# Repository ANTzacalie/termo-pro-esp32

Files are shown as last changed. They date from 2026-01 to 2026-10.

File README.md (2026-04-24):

# ESP32 Smart Thermostat (V1)

<p align="center">







</p>

A fully functional, smart thermostat built on the ESP32 platform using the ESP_NOW protocol for wireless communication. This unit features 6 programmable modes, a persistent flash-memory system, and an automated brightness control system.

## 💎 Features

- **Protocol:** ESP-NOW for fast, low-power communication with heating units.  
- **Storage:** All programs and settings are stored in Flash memory (NVS) to prevent data loss during power outages.  
- **Display:** 16x2 LCD providing real-time data and a menu-driven configuration system.  
- **Auto-Brightness:** Integrated photoresistor (LDR) logic that adjusts LCD backlight based on ambient light.  

- **Programs:**  
  - **Program B (Basic):** Pre-configured (Start: 21°C / Stop: 23°C).  
  - **Programs 1–5:** User-programmable (Empty by default).  
  - **Program 6/A:** Dedicated Comfort/Auto mode.  

---

## 🖥 User Interface Guide

### Main Interface [A]

This is the default screen. It displays the following layout:  

`T: vv.v H: vv.v PN XX:XX DAY[N] D/N O/F`

| Indicator | Description |
|---|---|
| T | Current Temperature (Celsius) |
| H | Relative Humidity (%RH) |
| P | Program Mode |
| N | Program ID Number |
| XX:XX | Current Time (Hours:Minutes) |
| DAY [N] | Current Day of the week (1–7) |
| D/N | Day / Night Status |
| O/F | Heating Status (On / Off) |

---

### Navigation & Settings [B]

To access the configuration menu, press and hold **Button 1** for **2 seconds**.  

> **Note:** Entering Interface [B] pauses the thermostat's main control logic until you exit.

#### Controls in Menus

- **Button 2:** Moves the cursor (indicated by an arrow `->`).  
- **Button 1:** Selects the highlighted option or increments values.  

#### Menu Options

- **SPG (Select Program):** Choose which of the 6 programs to activate. Selecting a program returns you to Menu [B].  

- **EPG (Edit Program):**  
  - Select the program you wish to modify.  
  - Line 1 shows the Program ID; Line 2 shows Start Temperature and Stop Temperature.  
  - Button 2 selects the value; Button 1 increments the temperature.  
  - **Save Logic:** After 10 seconds of inactivity, the data is saved to memory, set as the active program, and the system returns to Menu [B].  

- **ETM (Edit Time):**  
  - Modify Hour, Minute, and Day.  
  - Button 2 moves the cursor; Button 1 increments the value.  
  - **Save Logic:** Settings save automatically after 10 seconds of inactivity.  

- **EXIT:** Returns to the Main Interface [A].  

---

## 🛠 Special Commands & Manual Overrides

These actions are performed directly from the Main Interface [A] using timed button presses:

| Action | Button Combo | Duration | Result |
|---|---|---|---|
| System Restart | Button 1 + Button 2 | 15 Seconds | Device reboots |
| Manual Mode | Button 2 | 5 Seconds | Disables auto-logic and active program |
| Manual OFF | Button 2 | 5 Seconds | While in Manual Mode: Turns off the heating module |
| Manual ON | Button 1 + Button 2 | 10 Seconds | While in Manual Mode: Turns on the heating module |
| Exit Manual | Button 2 | 10 Seconds | Cancels manual control and restores Auto Program logic |

---

## 🚀 Future Roadmap - V2 ;)
- An PCB and 3D printed case, also improved functionalities and better starting module microcontroller.
- 📱 **Mobile Application:** A dedicated app for Android to control the thermostat remotely via Bluetooth (BLE). This will allow for easy program editing and manual overrides without using the physical buttons.

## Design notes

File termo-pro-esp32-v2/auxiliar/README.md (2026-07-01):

**** Thermostat Unit ****

- 1 x WC1602A Display;
- 1 x ESP32WROOM32-NodeMCU32S 38pin Devkit;
- 1 x DHT11 Temperature&Humidity Sensor;
- 1 x Buzzer;
- 1 x 8PIN_P2.54mm USB-C Soldered module;
- 1 x 1N4007 Diode(smaller one work too);
- 4 x 6mm tactile buttons;
- 2 x 10k resistors;
- 1 x 1k resistor;
- 1 x 330 ohm resistor;
- 1 x 10k RM65 potentiometer;
- 1 x 10k LDR Photoresistor;
- 2 x PN2222A BJT NPN Transistors;
- 2 x 50V 220nF capacitors;
- 1 x 16V 680uF capacitor;
- 1 x 25V 220uF capacitor;

**** Starting Unit ****

- 1 x ESP32-C3-Supermini Devkit 16pin;
- 1 x 8PIN_P2.54mm USB-C Soldered module;
- 1 x 220 ohm resistors; *P1*
- 2 x 50 ohm resistor;  *P1*
- 1 x 330 ohm resistor;
- 1 x 10k resistor;
- 1 x 25V 220uF capacitor;
- 1 x 50V 220nF capacitor;
- 1 x 10V 470uF capacitor;
- 1 x 12mm tactile LED(1.8V) button; *P1*
- 1 x PN2222A BJT NPN Transistor;
- 1 x Rectangular GREEN LED(3V); *P1*
- 1 x Rectangular RED LED(3V); *P1*
- 2 x Screw Terminal Blocks P5.08 - 5mm;
- 1 x 1N4007 Diode;
- 1 x SRD_FORM_C 5V Relay;

*P1* -> Resistor values for each LED is calculated based on the internal diode forward voltage using Ohm Law !
I recommand having LED of the same forward voltage, so you can get equal brightness.

///////////////////////////////////// ELECTRICAL IMPLEMENTATION ////////////////////////////////////

--------- Starting Unit ---------

- Relay flyback diode -> diode that can handle minimum 200mA, I have chosen 1N4007 because is cheap and easy to find, and handles a maximum of 1A.
- PN2222A NPN BJT Transistor, its cheap and good for general use as a switch, using a MOSFET is more expensive.
- Resistance of the transistor that drives the relay is calculated using Ohm law, the relay takes around 80mA, taking a B = 10 as minimum , we need ~7-8 mA in transistor base , an 330 Ohm resistance is used because:
I = U / R => I = (3.3 - 0.7(TB)) / 330 => I ~ 7.8 mA , so 330 ohm is enough to saturate the transistor for optimal operation.
- 10k B3950A thermistor, to be read by ADC pin requires another 10k resistor to form a tension divider for reading to be possible.
- 12.5mm LED button requires an 470 ohm resistor because internal diode uses 1.8V an 220 ohm resistance is used => I = 3.3 - 1.8 / 220 => I = 6.8mA , that is decent in brightness.
- The 2 LED , green and red, used 50 ohm used for both , because red is 3V and green is also 3V , so they are close in luminosity, also current is under 7mA per pin.
- Capacitor values C1,C2 and C3:
*C1 is the main capacitor that is positioned at the begining of the USB-C 5VDC, the value of 220uF is chosen to surpress current spikes for the general circuit(not the ESP32-C3-Supermini, not complete);
*C3 is the main capacitor positioned close to the ESP32-C3 with a value of 470uF , this and C1 in combination is to surpress the current spikes of the ESP32-C3, as calculated by tge formula:
C = I * dt / dV => C = 0.335A(spike current) * 0.0005s(500us) / 0.3V(averge) => C = 558uF, this value is not easy to find so C3 is 470uF and C1 compensates, capacitor in paralel sum capacitance, so C1,3 = 690uF, that is enough;
*C2 the 220nF capacitor si placed very close to the ESP32 5V(VIN) pin , this is used for bypass.

Total Power Consumption(P = I x V) => 335mA x 5V + 80mA x 5V + 2x6mA x 0.3V + 200uA x 3.3V + 6.8mA x 1.5V => P =  2.089W ~ 2.1W

--------- Termostat Unit ---------

- WC1602A display has a 10k Potentiometer for contrast control.
- Buzzer flyback diode 1N4007, same reason as for the relay.
- Transistor BJT NPN PN2222A driving the buzzer has a base resistance of 1kOhm, enough to saturate it I = 3.3 - 0.7 / 1kOhm => I ~ 2.6mA , buzzer takes from 15mA to 30mA , so 2.6mA is enough for saturation.
- Transistor BJT NPN PN2222A driving the display brightness usign PWM, used base resistor 330Ohm , as display maximum current is around 80mA.
- 10k LDR has anoter 10k resistance for tension divider.
- 10k RM65 Potentiometer for the display.
- DHT11 raw module needs an 10k pull-up to 3.3V, so to be safe for GPIO.
- Capacitors values C1,C2,C3 and C4:
*C1&C3 ESP32WROOM32-NodeMCU32S has current spikes during WIFI operations to up to 500mA, calculated electrolithic capacitance is 833uF, so 680uF at the 5V VIN of the esp32 and 220uF at the USB-C 5VDC;
*C2 the 220nF capacitor si placed very close to the ESP32 5V(VIN) pin , this is used for bypass.
*C4 another 220nF capacitor is again for bypass and stability of the DHT11 sensor.

Total Power Consumption(P = I x V) => 500mA x 5V + 25mA x 5V + 2.5mA x 5V + 80mA x 5V + 200uA x 3.3V => P = 3.038W ~ 3.05W

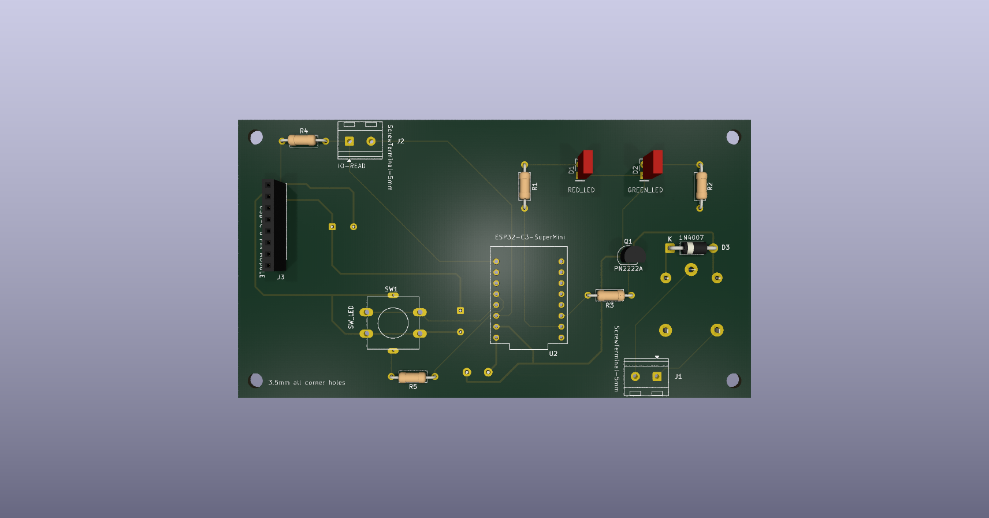
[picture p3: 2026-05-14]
termo-pro-esp32-v2/docs/screenshots/starting_module-v2.png

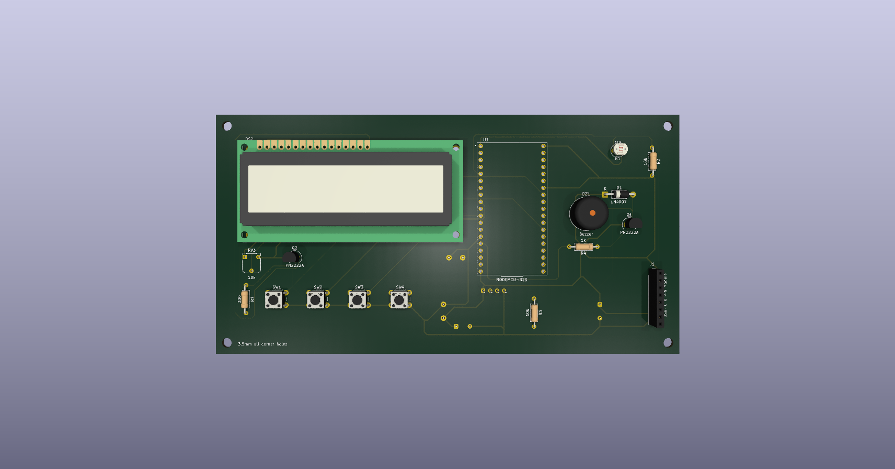
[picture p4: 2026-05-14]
termo-pro-esp32-v2/docs/screenshots/thermostat_v2.png

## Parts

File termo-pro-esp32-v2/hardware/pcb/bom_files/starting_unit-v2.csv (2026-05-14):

Reference | Qty | Value | DNP | Exclude from BOM | Exclude from Board | Footprint | Datasheet | Description
C1 | 1 | 25V 220uF |  |  |  | Capacitor_THT:CP_Radial_D8.0mm_P5.00mm |  | Polarized capacitor
C2 | 1 | 50V 220nF |  |  |  | Capacitor_THT:C_Disc_D11.0mm_W5.0mm_P5.00mm |  | Unpolarized capacitor
C3 | 1 | 10V 470uF |  |  |  | Capacitor_THT:CP_Radial_D8.0mm_P5.00mm |  | Polarized capacitor
D1,D2 | 2 | LED |  |  |  | LED_THT:LED_Rectangular_W5.0mm_H2.0mm |  | Light emitting diode
D3 | 1 | 1N4007 |  |  |  | Diode_THT:D_DO-41_SOD81_P10.16mm_Horizontal | http://www.vishay.com/docs/88503/1n4001.pdf | 1000V 1A General Purpose Rectifier Diode, DO-41
J1,J2 | 2 | Screw_Terminal_01x02 |  |  |  | TerminalBlock_RND:TerminalBlock_RND_205-00232_1x02_P5.08mm_Horizontal |  | Generic screw terminal, single row, 01x02, script generated (kicad-library-utils/schlib/autogen/connector/)
J3 | 1 | Conn_01x08_Pin |  |  |  | Connector_PinSocket_2.54mm:PinSocket_1x08_P2.54mm_Vertical |  | Generic connector, single row, 01x08, script generated
K1 | 1 | SANYOU_SRD_Form_C |  |  |  | Relay_THT:Relay_SPDT_SANYOU_SRD_Series_Form_C | http://www.sanyourelay.ca/public/products/pdf/SRD.pdf | Sanyo SRD relay, Single Pole Miniature Power Relay,
Q1 | 1 | PN2222A |  |  |  | Package_TO_SOT_THT:TO-92_Inline | https://www.onsemi.com/pub/Collateral/PN2222-D.PDF | 1A Ic, 40V Vce, NPN Transistor, General Purpose Transistor, TO-92
R1,R2 | 2 | 50 |  |  |  | Resistor_THT:R_Axial_DIN0207_L6.3mm_D2.5mm_P10.16mm_Horizontal |  | Resistor
R3 | 1 | 330 |  |  |  | Resistor_THT:R_Axial_DIN0207_L6.3mm_D2.5mm_P10.16mm_Horizontal |  | Resistor
R4 | 1 | 10k |  |  |  | Resistor_THT:R_Axial_DIN0207_L6.3mm_D2.5mm_P10.16mm_Horizontal |  | Resistor
R5 | 1 | 220 |  |  |  | Resistor_THT:R_Axial_DIN0207_L6.3mm_D2.5mm_P10.16mm_Horizontal |  | Resistor
SW1 | 1 | SW_Push_LED |  |  |  | Button_12mm_LED_THT:SW_PUSH-12mm |  | Push button switch with LED, generic
U2 | 1 | ESP32-C3_SUPERMINI_TH |  |  |  | ESP32-C3_SUPERMINI_TH:MODULE_ESP32-C3_SUPERMINI_TH |  | Super tiny ESP32-C3 board

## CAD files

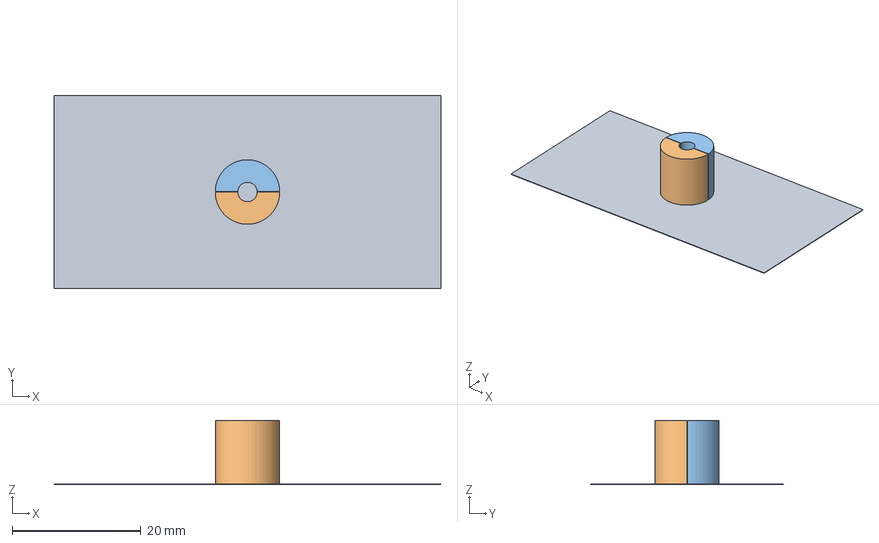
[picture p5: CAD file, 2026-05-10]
termo-pro-esp32-v2/enclosure_3d/cable_clipper/cable_clipperFCStd.FCStd
60.0 x 30.0 x 10.0 mm
Slice.1
Slice.2

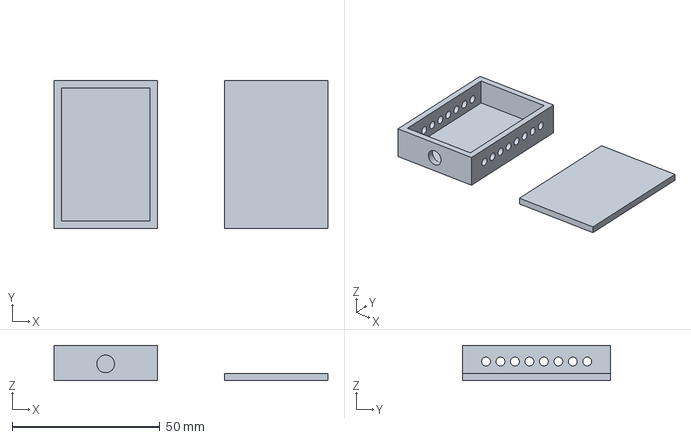
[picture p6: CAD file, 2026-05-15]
termo-pro-esp32-v2/enclosure_3d/external_temperature_sensor/external_temperature_sensor_enclosure.FCStd
92.8 x 50.0 x 12.0 mm

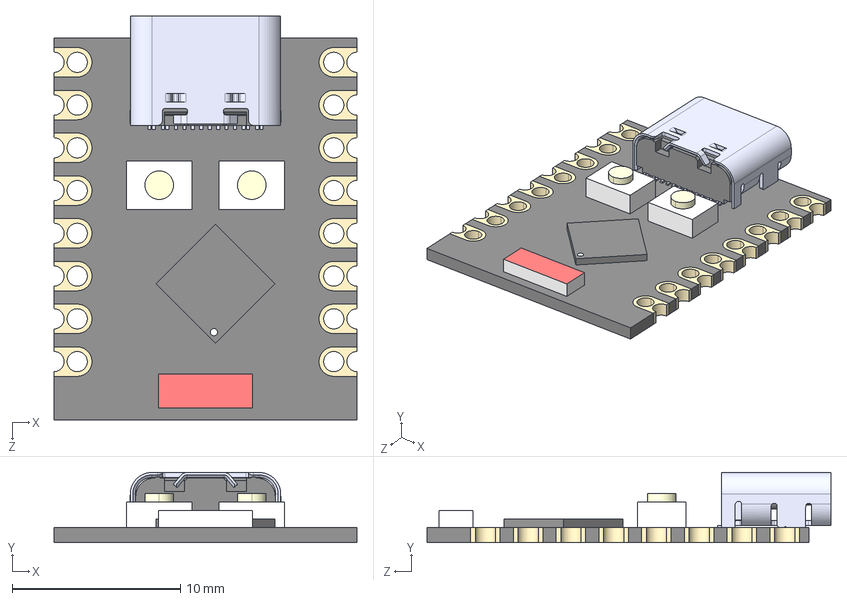
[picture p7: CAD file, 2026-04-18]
termo-pro-esp32-v2/hardware/symbols&footprints/ESP32-C3_SUPERMINI_TH/ESP32-C3_SUPERMINI_TH.step
18.0 x 4.16 x 24.0 mm
Board c3mini
USB C
components (other)^ESP32-C3 SuperMini

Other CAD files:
termo-pro-esp32-v2/enclosure_3d/external_temperature_sensor/external_temperature_sensor_enclosure-BodyHole.3mf
termo-pro-esp32-v2/enclosure_3d/cable_clipper/cable_clipperFCStd.3mf

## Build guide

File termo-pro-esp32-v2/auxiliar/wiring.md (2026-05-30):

///!/// This is only for breadboard assembly, not required for PCB as its already done, not including non-GPIO pins! ///!/// 

**** ESP32-C3-SuperMini Starting Unit GPIO PINS USE ****

- GPIO0 -> external temperature sensor before 10k resistor;
- GPIO1 -> unconected;
- GPIO2 -> unconected;
- GPIO3 -> resistor -> 12mm LED button(+);
- GPIO4 -> 12mm LED button(logic);
- GPIO5 -> resistor -> green_led;
- GPIO6 -> resistor -> red_led;
- GPIO7 -> resistor -> PN2222A base;
- GPIO8,9,10,20,21 unconected
- 5V(VIN) to 5V ~ 6V;
- 3.3V -> external temperature sensor(+);
- GND -> GND;

**** ESP32-NodeMCU32S Thermostat Unit GPIO PINS USE ****

- GPIO21 -> DHT11 DATA;
- GPIO22 -> resistor -> PN2222A Base(Display);
- GPIO23,25,26,27 -> buttons;
- GPIO13 -> resistor -> PN2222A Base(Buzzer);
- GPIO19 -> E;
- GPIO18 -> RS;
- GPIO17 -> D7;
- GPIO4 -> D4;
- GPIO14 -> D5;
- GPIO16 -> D6;
- GPIO34 -> between 10k LDR and 10k resistor;
- 5V -> 5V ~ 6V;
- 3.3V -> 10k LDR;

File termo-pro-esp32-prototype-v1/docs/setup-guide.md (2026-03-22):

# Setup Guide

## 1. Overview

This document describes the hardware setup and GPIO configuration for:

- Starting Module (Ignition Control)
- Intelligent Thermostat Module

All testing was performed using the ESP32-WROOM-32 DevKit.
For the Starting Module an ESP8266 can be used too with proper adaptations.

---

# Hardware Assembly

The prototype was assembled using two T830 breadboards.

Follow the electrical schematic provided in the PDF or KiCad project files for exact wiring.
On the  electrical schematics there is an symbol marked U3, it represents the MB-V2 Breadboard power supply, you can use any other power supply, but make sure it can output at least 600mA !

For easier assembly:
- Use large breadboards for better routing.
- Keep power and signal lines separated where possible.
- Keep relay wiring isolated from low-voltage logic wiring.

For a permanent installation, design and manufacture a PCB based on the schematic and solder all components.

# Thermostat Module – GPIO Configuration

The thermostat ESP32 uses the following pins:

* DHT11 (Temperature & Humidity Sensor)
  + GPIO 23  

* LCD Display (Parallel Interface)
  + GPIO 4
  + GPIO 5
  + GPIO 16
  + GPIO 17
  + GPIO 18
  + GPIO 19

* LCD Backlight Brightness (PWM)
  + GPIO 12  

* Push Buttons
  + GPIO 32  
  + GPIO 33  

* Photoresistor (LDR – Analog Input)
  + GPIO 34  

---

# Starting Module – GPIO Configuration

* Relay Control
  + GPIO 17  

If using a pre-made relay module:
- Only GPIO 17 is required.
- Status LEDs are already integrated on the module.

If building the relay driver manually:
- Two additional GPIO pins are required for LED indicators.
- LEDs must also be defined in the firmware.

---

# Electrical Considerations

Maximum draw recommended GPIO current:  
12 mA per pin on any component.  

Ensure:
- Proper base resistor sizing for transistor switching.
- Common ground between ESP32 and relay driver circuit.
- Flyback diode across relay coil.

---

# Manual Relay Driver Notes (Without Pre-Made Module)

The startingModule.ino file does not include control logic for the two schematic LEDs.  
If using the discrete version, manually define the LED pins and add control logic. Comments are already included in the code for guidance.

Relay switching configuration:

- NPN transistor used (low-side switching)
- ESP32 logic level: 3.3 V

Reason:
  -Most PNP high-side relay modules require 5 V logic for reliable operation.  
  -Using an NPN transistor ensures proper switching with 3.3 V control signals.

Recommended base current:  
2–3 mA minimum to ensure transistor saturation.

Base resistor values tested:
- 1 kΩ (used)
- 470 Ω (acceptable)
- 330 Ω (acceptable)

Flyback diode:
- 1N4007 (used)
- 1N4001 (compatible)
- 1N4148 (acceptable for small relay coils)

---

---

# Boiler Connection

The relay connects to the heating boiler using:

- NO–COM terminals  
  or  
- TA/TA terminals (depending on boiler labeling)

Ensure the boiler control circuit is voltage-free (dry contact) before connecting.

---

# Important Warning
Different ESP32 variants may have different GPIO capabilities and restrictions.

Before wiring:
- Verify which pins support PWM.
- Verify which pins support ADC.
- Avoid strapping pins unless properly understood.

# *** WARNING ***
- Incorrect wiring may permanently damage the microcontroller.
- It is recomanded to assemble by step and test.

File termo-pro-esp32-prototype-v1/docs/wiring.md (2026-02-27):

Starting Module – Ignition Control

  | Signal Source | Component  | Value / Type  | Connected To          | Purpose               |
  | ------------- | ---------- | ------------- | --------------------- | --------------------- |
  | ESP32 GPIO21  | R3         | 1 kΩ          | Q1 Base               | Base current limiting |
  | Q1            | PN2222A    | NPN BJT       | Relay Coil (K1)       | Low-side switching    |
  | D3            | 1N4007     | Flyback diode | Across Relay Coil     | Back-EMF protection   |
  | K1            | SANYOU SRD | Relay         | Dry Contact Terminals | Load isolation        |

Intelligent Thermometer / Thermostat Module   

  | Source     | Component    | Value | Connected To | Purpose             |
  | ---------- | ------------ | ----- | ------------ | ------------------- |
  | 5V         | RV1          | 10 kΩ | LCD V0       | Contrast adjustment |
  | ESP32 GPIO | Q1 (PN2222A) | NPN   | LCD K(-)     | Backlight switching |
  
Sensors and Inputs

  | Device          | Connection      | ESP32 Pin    | Notes                  |
  | --------------- | --------------- | ------------ | ---------------------- |
  | DHT11           | DATA            | GPIO16       | Temperature / Humidity |
  | Photoresistor   | Voltage Divider | GPIO32 (ADC) | Light sensing          |
  | R2              | 10 kΩ           | GPIO32 → GND | Divider resistor       |
  | Push Button SW1 | Digital Input   | GPIO         | User input             |
  | Push Button SW2 | Digital Input   | GPIO         | User input             |

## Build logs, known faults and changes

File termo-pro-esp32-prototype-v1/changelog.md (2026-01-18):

Initial Release

Date: January 16, 2026 Tag: v1.0.0

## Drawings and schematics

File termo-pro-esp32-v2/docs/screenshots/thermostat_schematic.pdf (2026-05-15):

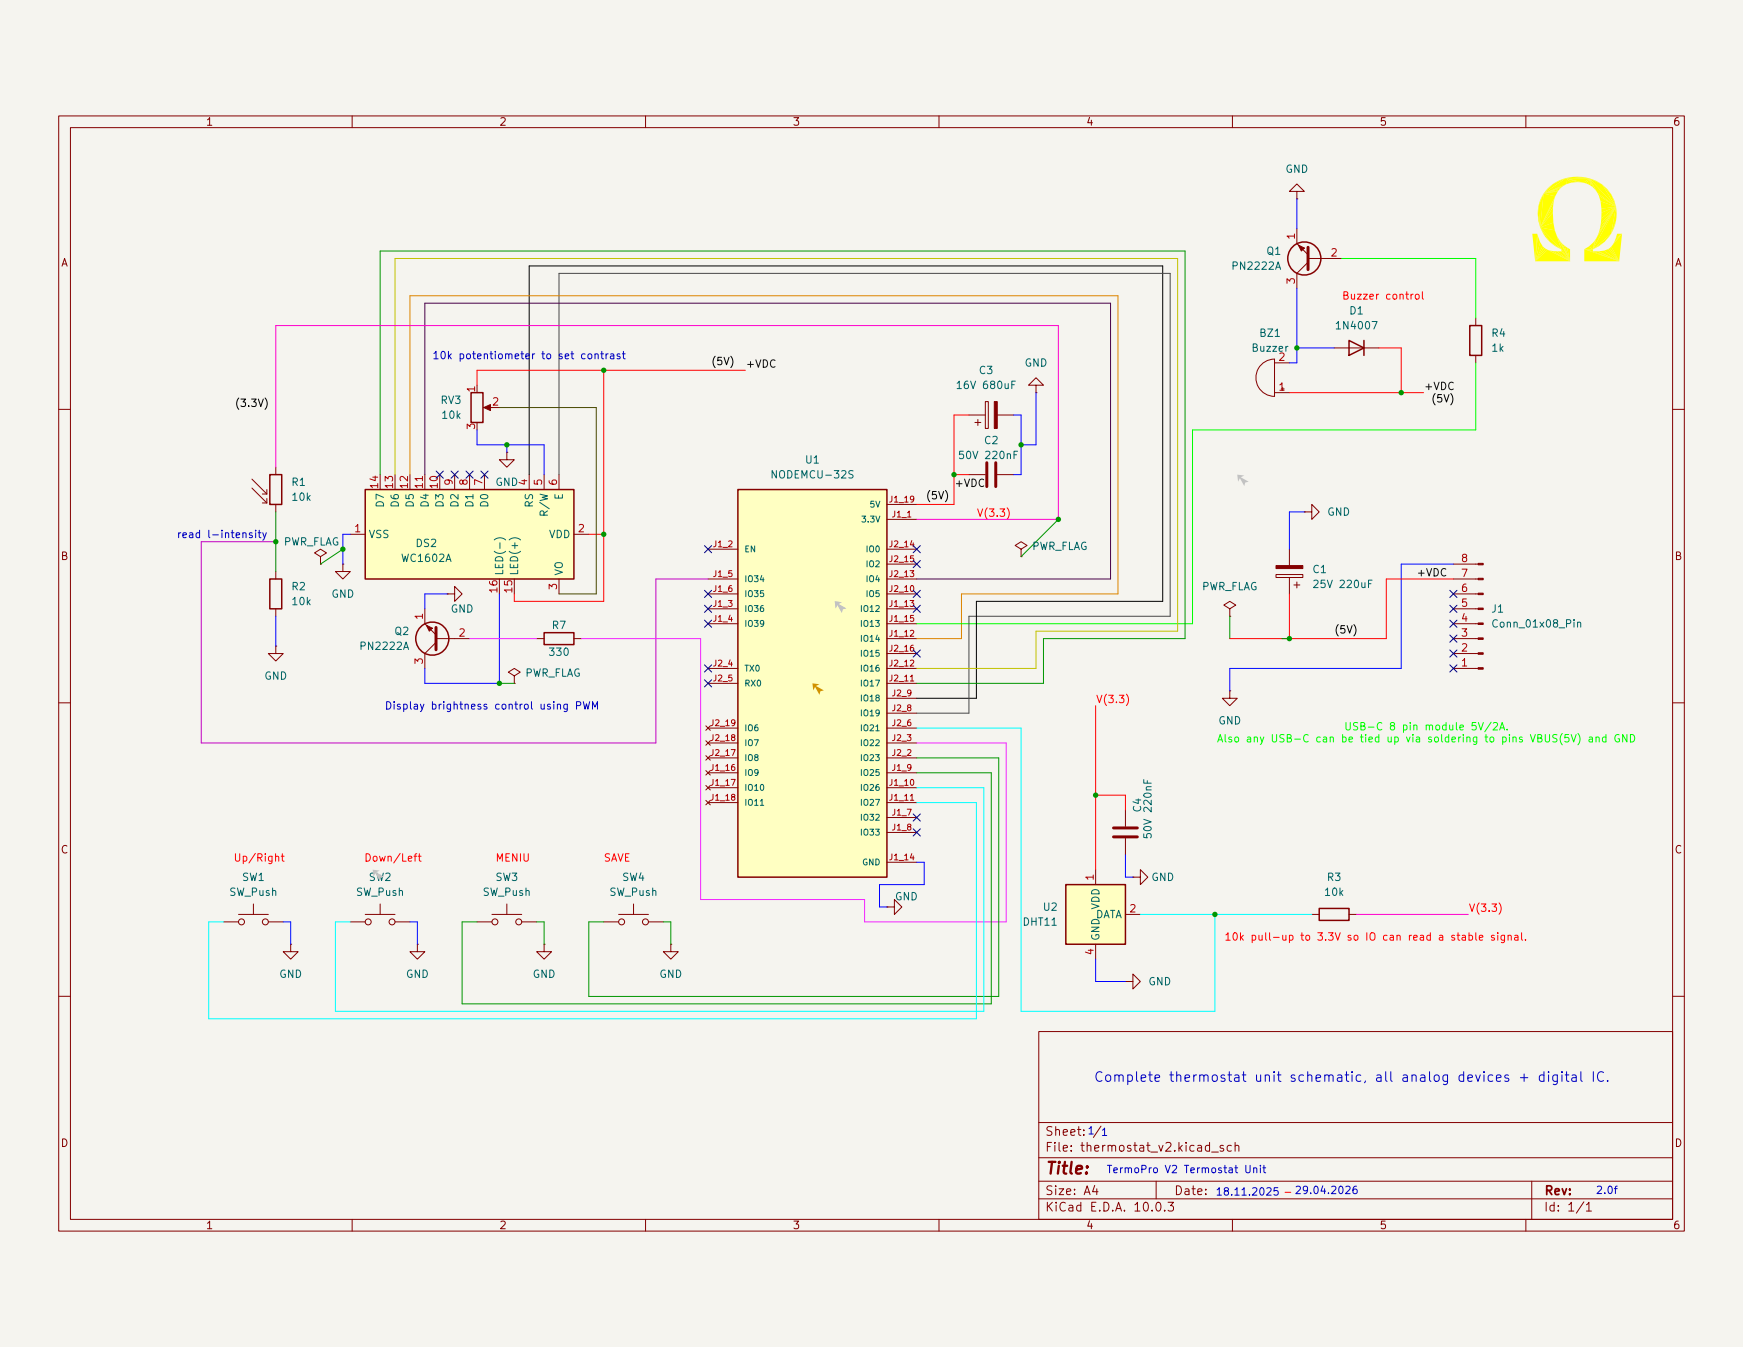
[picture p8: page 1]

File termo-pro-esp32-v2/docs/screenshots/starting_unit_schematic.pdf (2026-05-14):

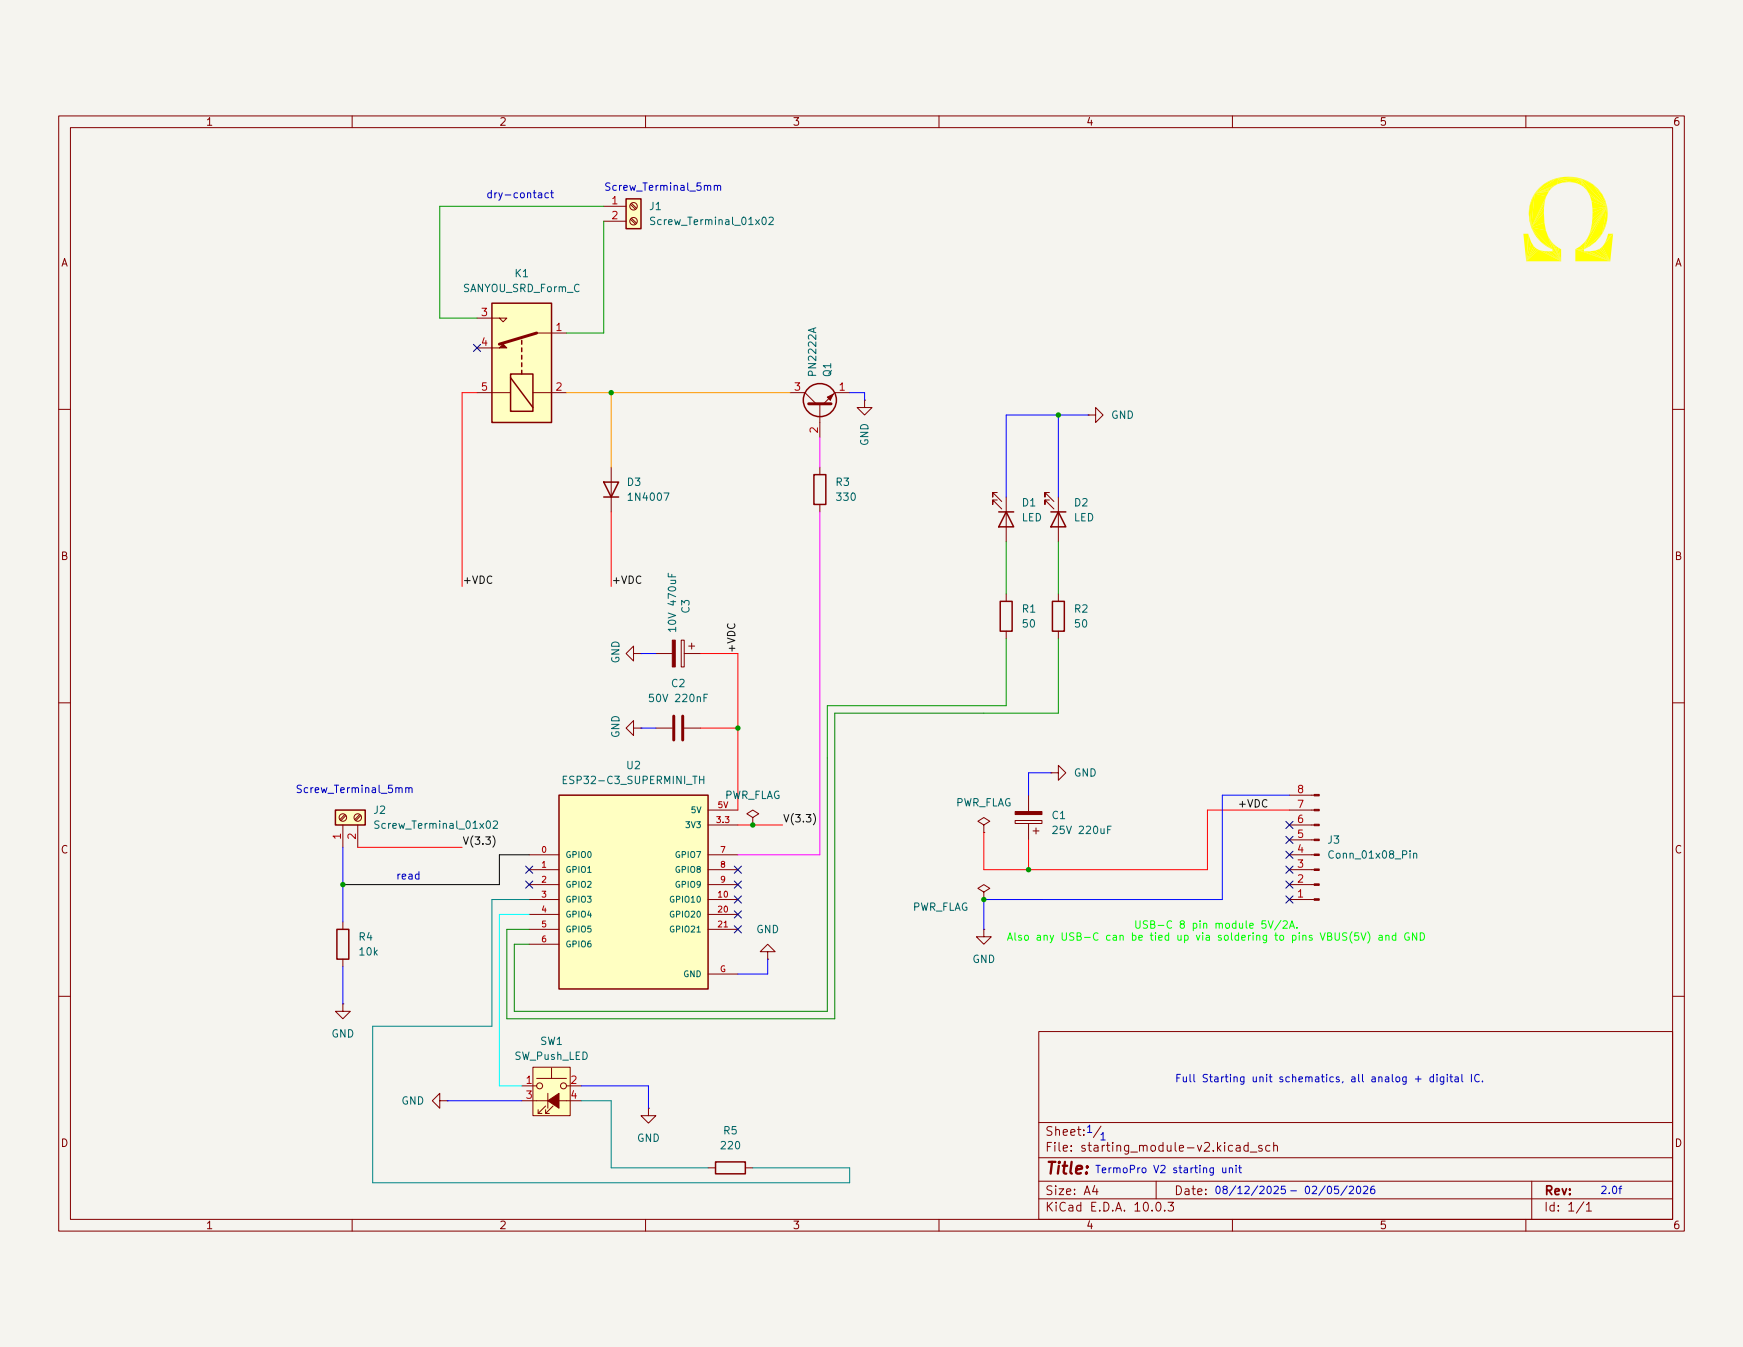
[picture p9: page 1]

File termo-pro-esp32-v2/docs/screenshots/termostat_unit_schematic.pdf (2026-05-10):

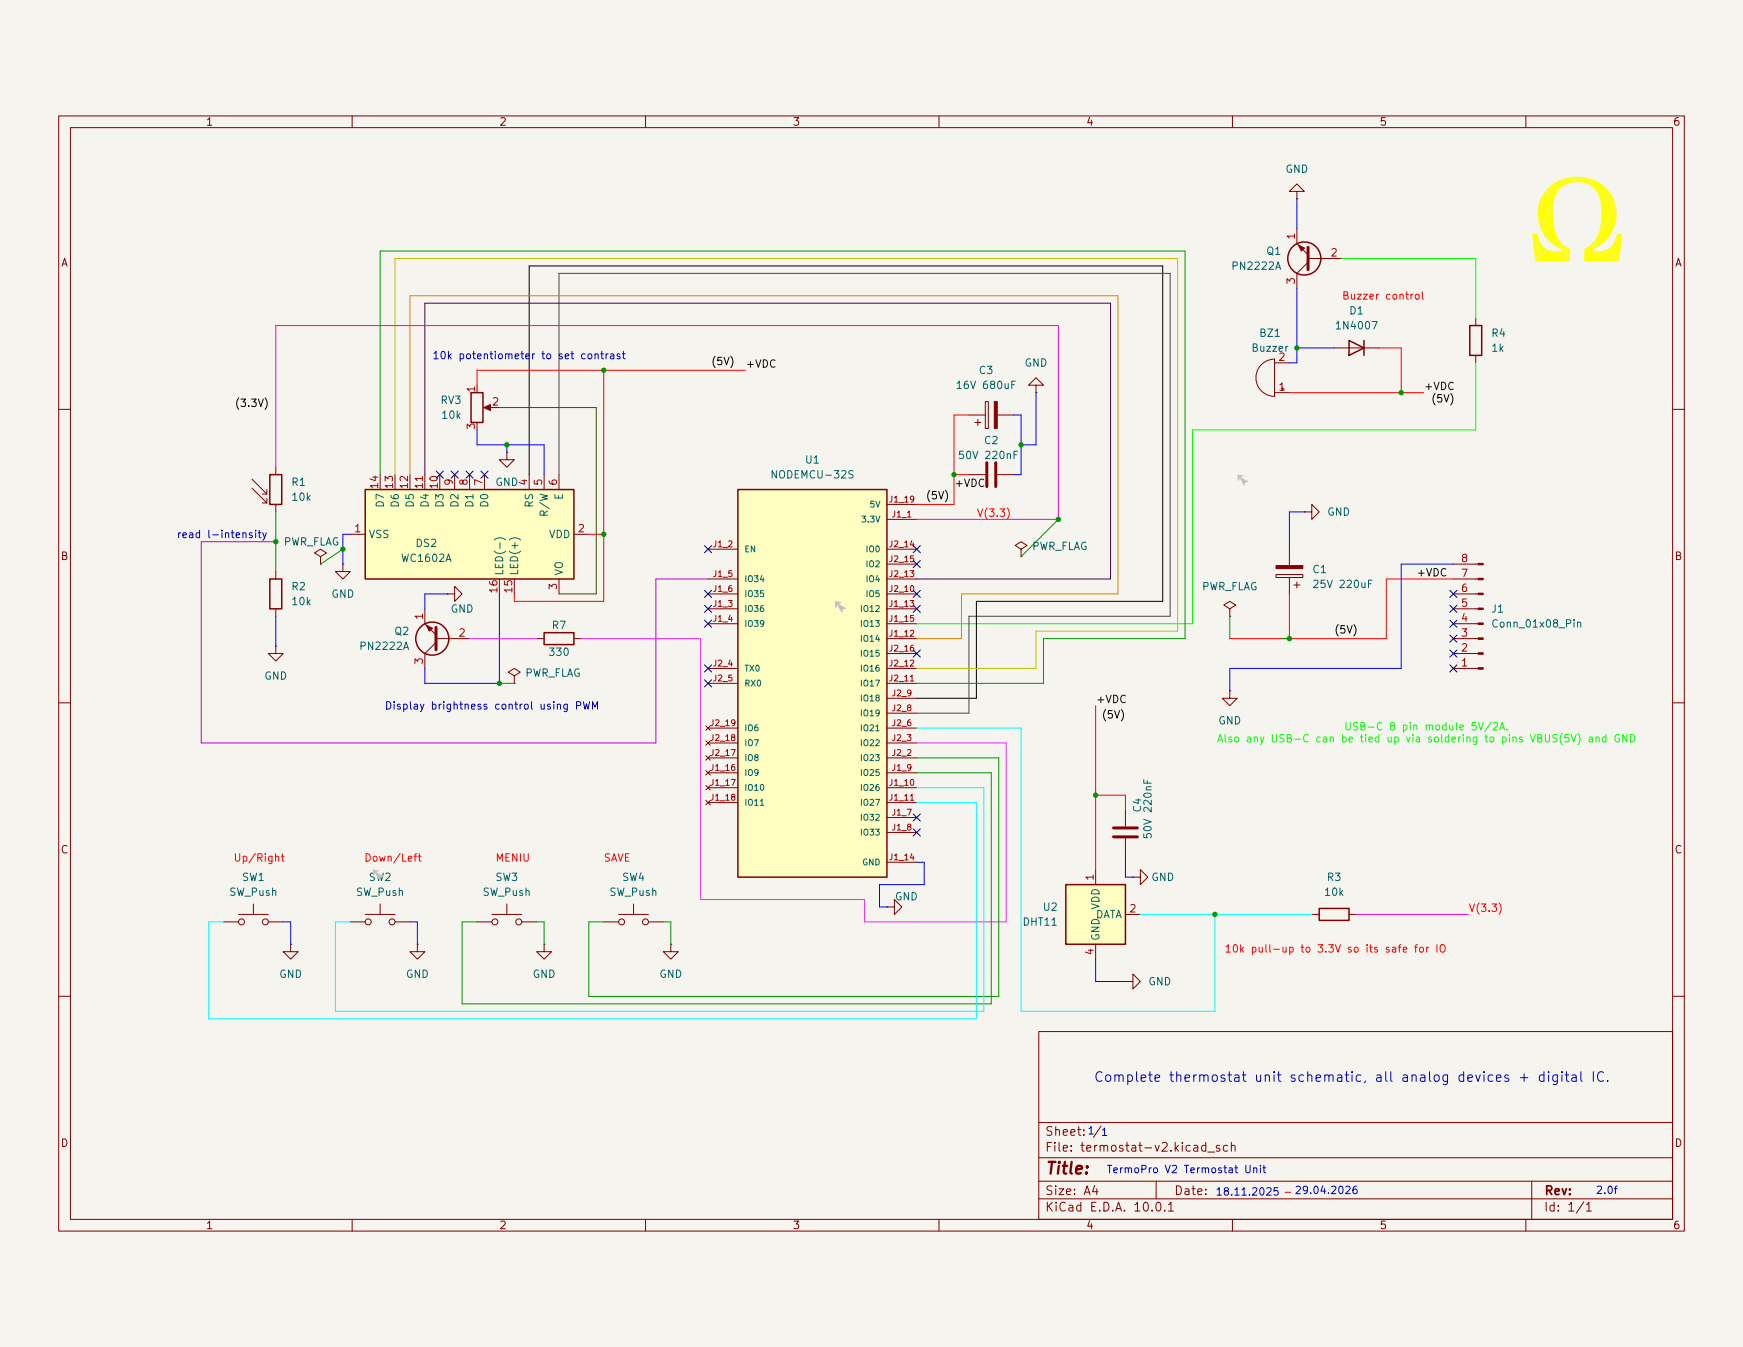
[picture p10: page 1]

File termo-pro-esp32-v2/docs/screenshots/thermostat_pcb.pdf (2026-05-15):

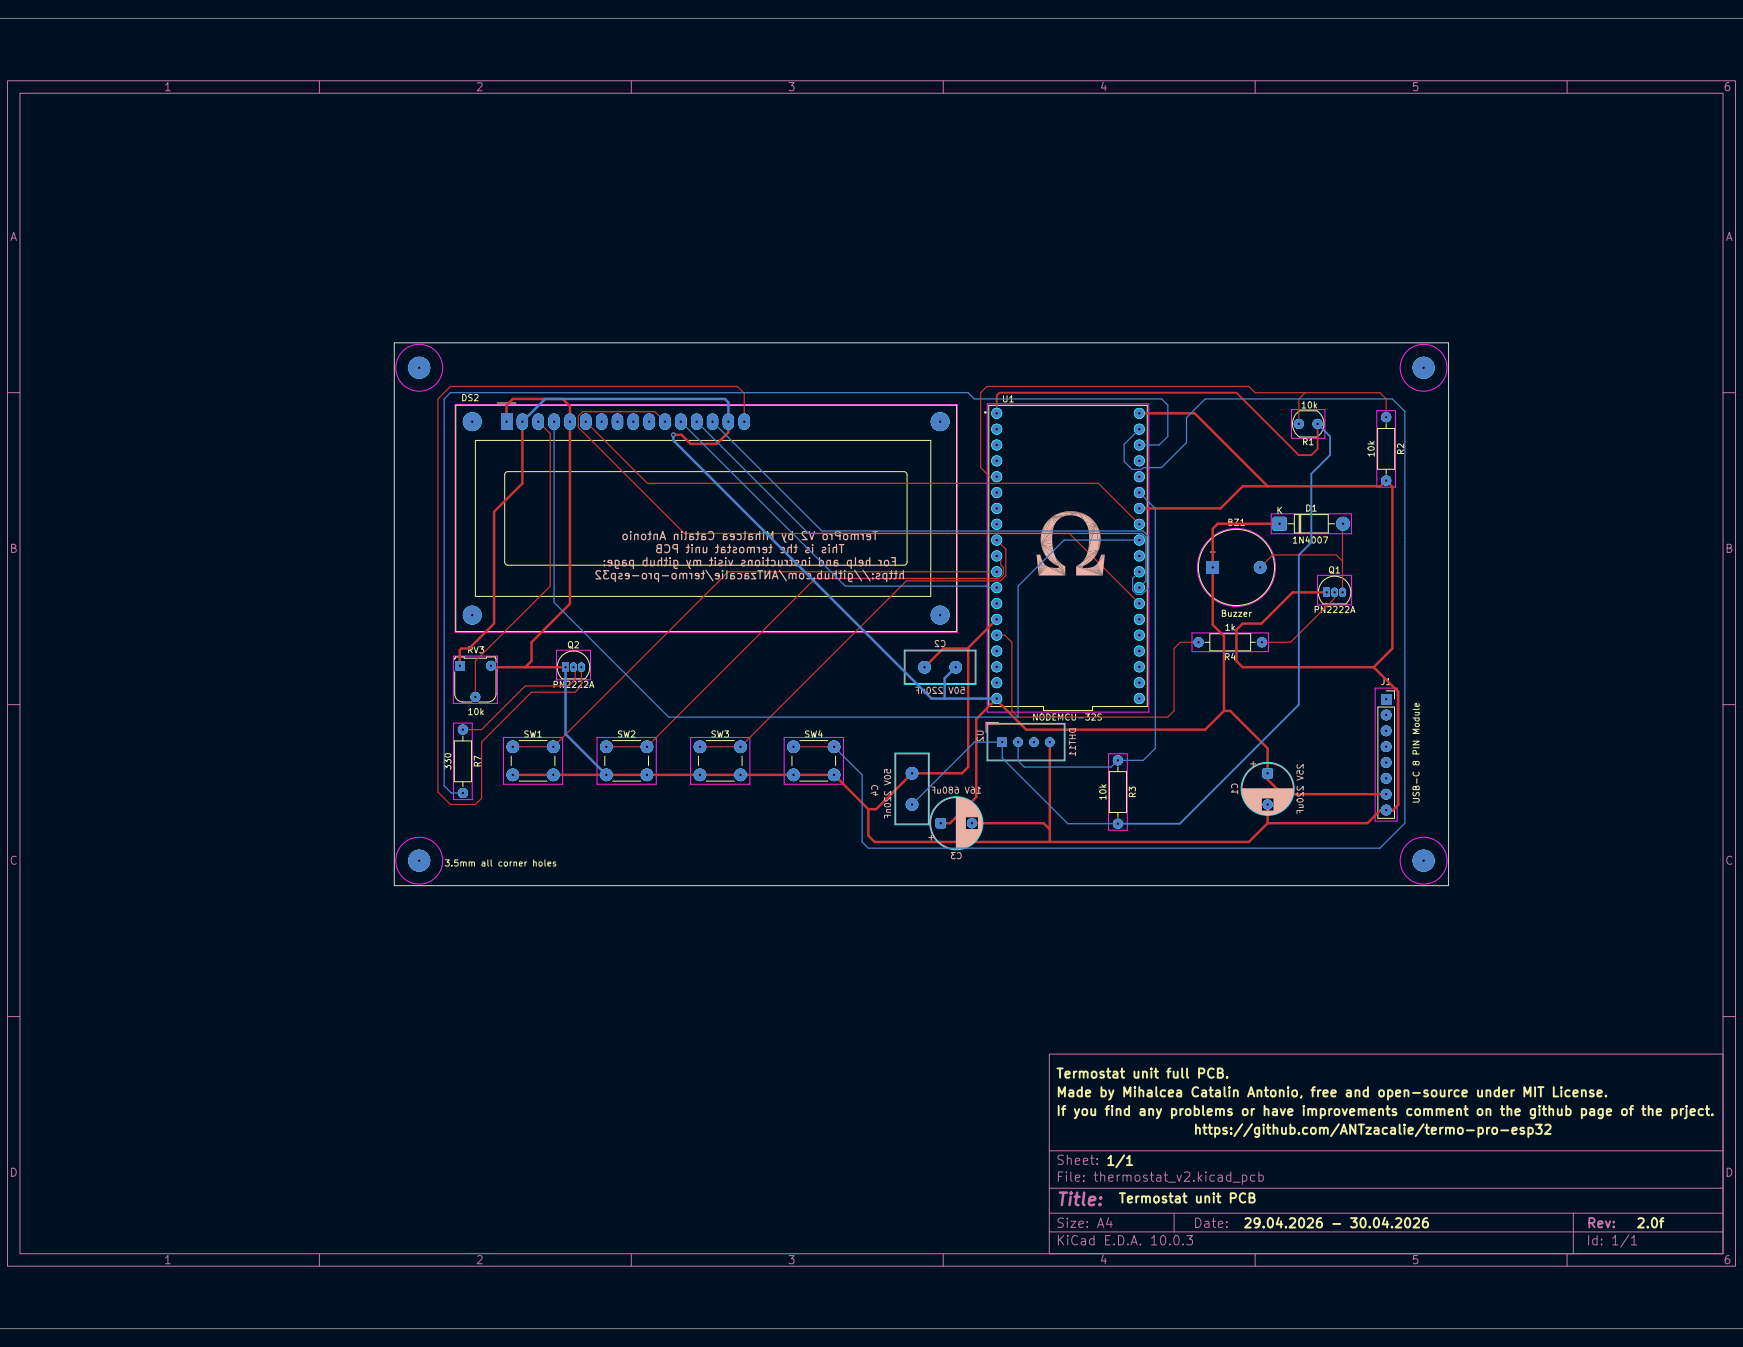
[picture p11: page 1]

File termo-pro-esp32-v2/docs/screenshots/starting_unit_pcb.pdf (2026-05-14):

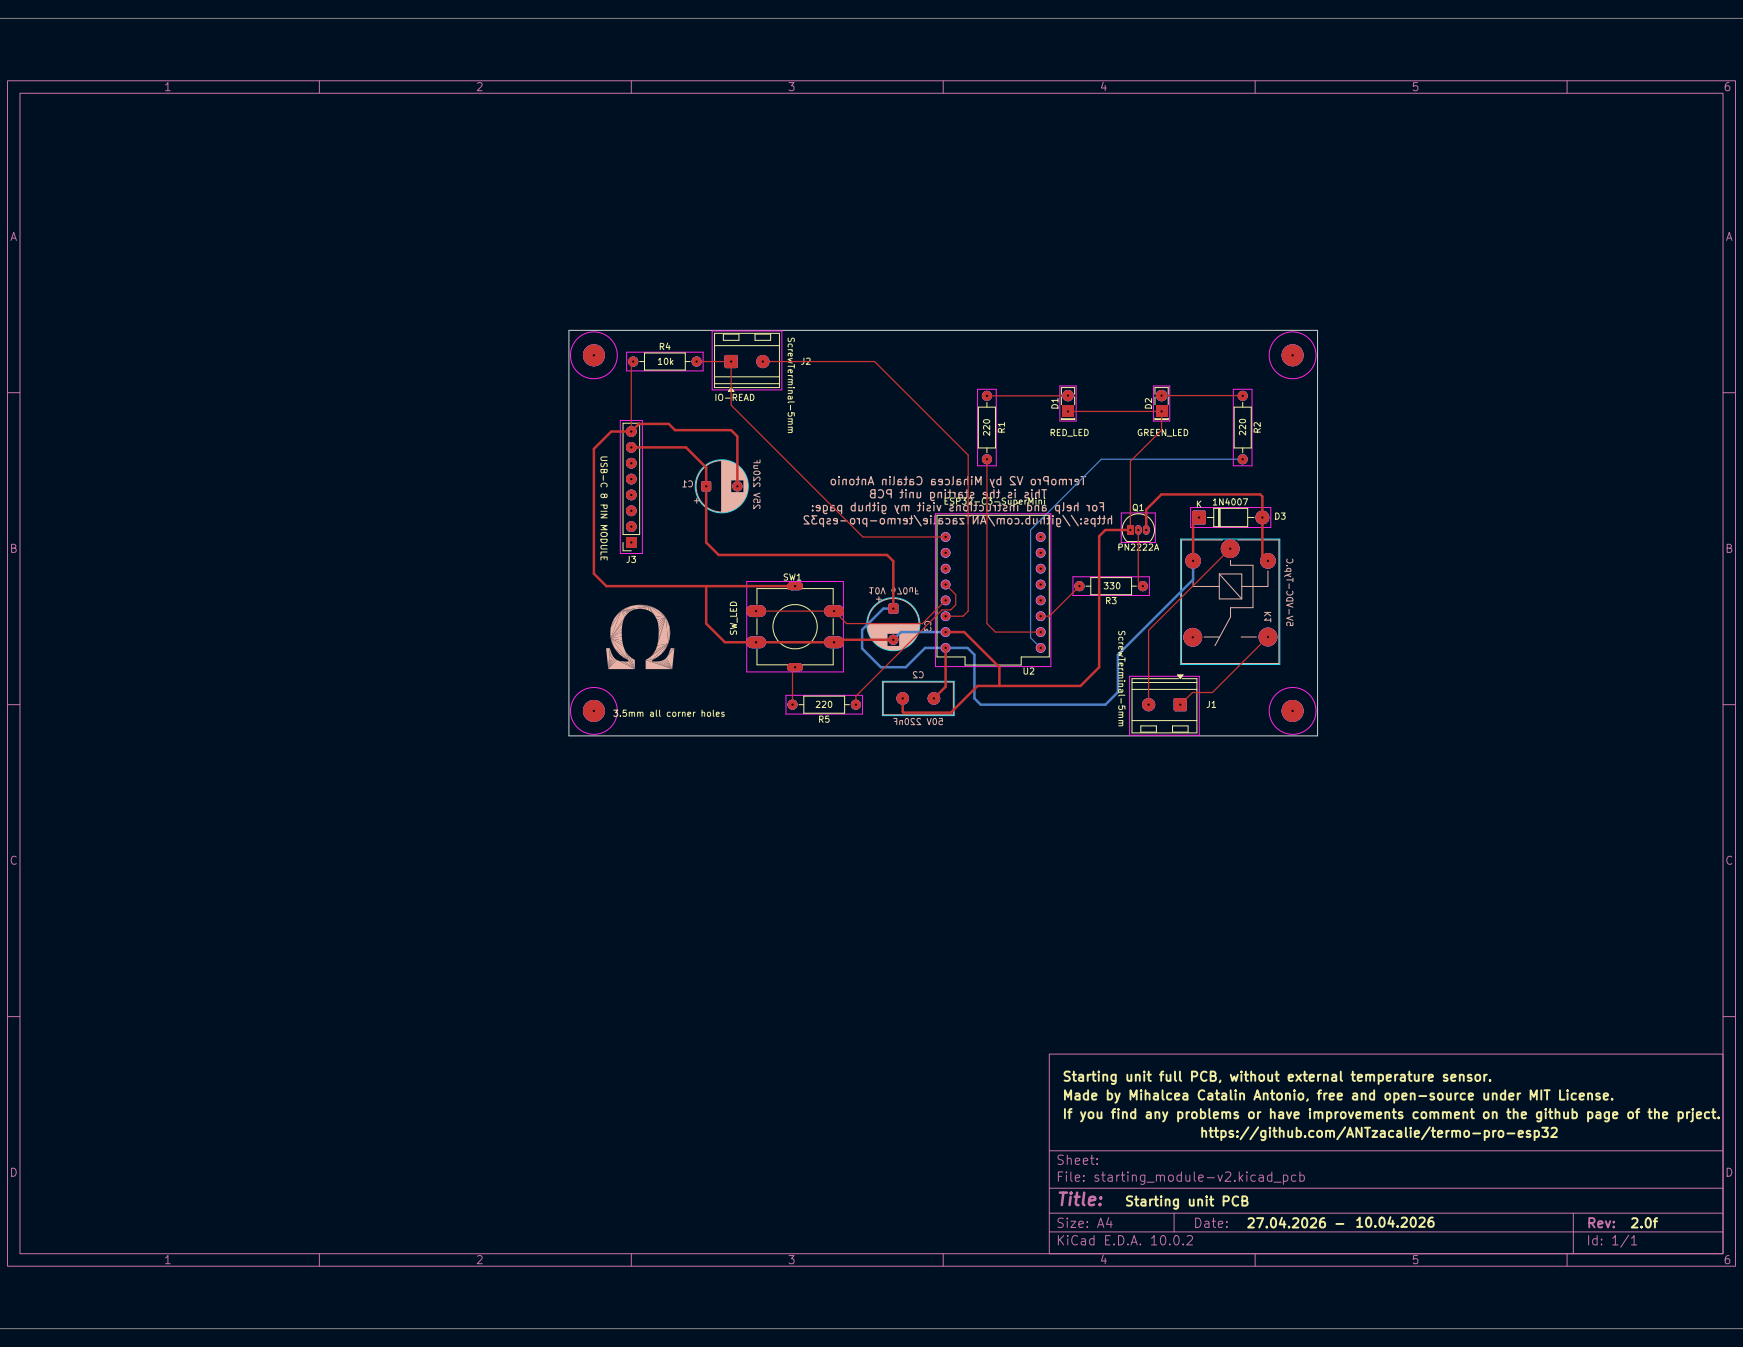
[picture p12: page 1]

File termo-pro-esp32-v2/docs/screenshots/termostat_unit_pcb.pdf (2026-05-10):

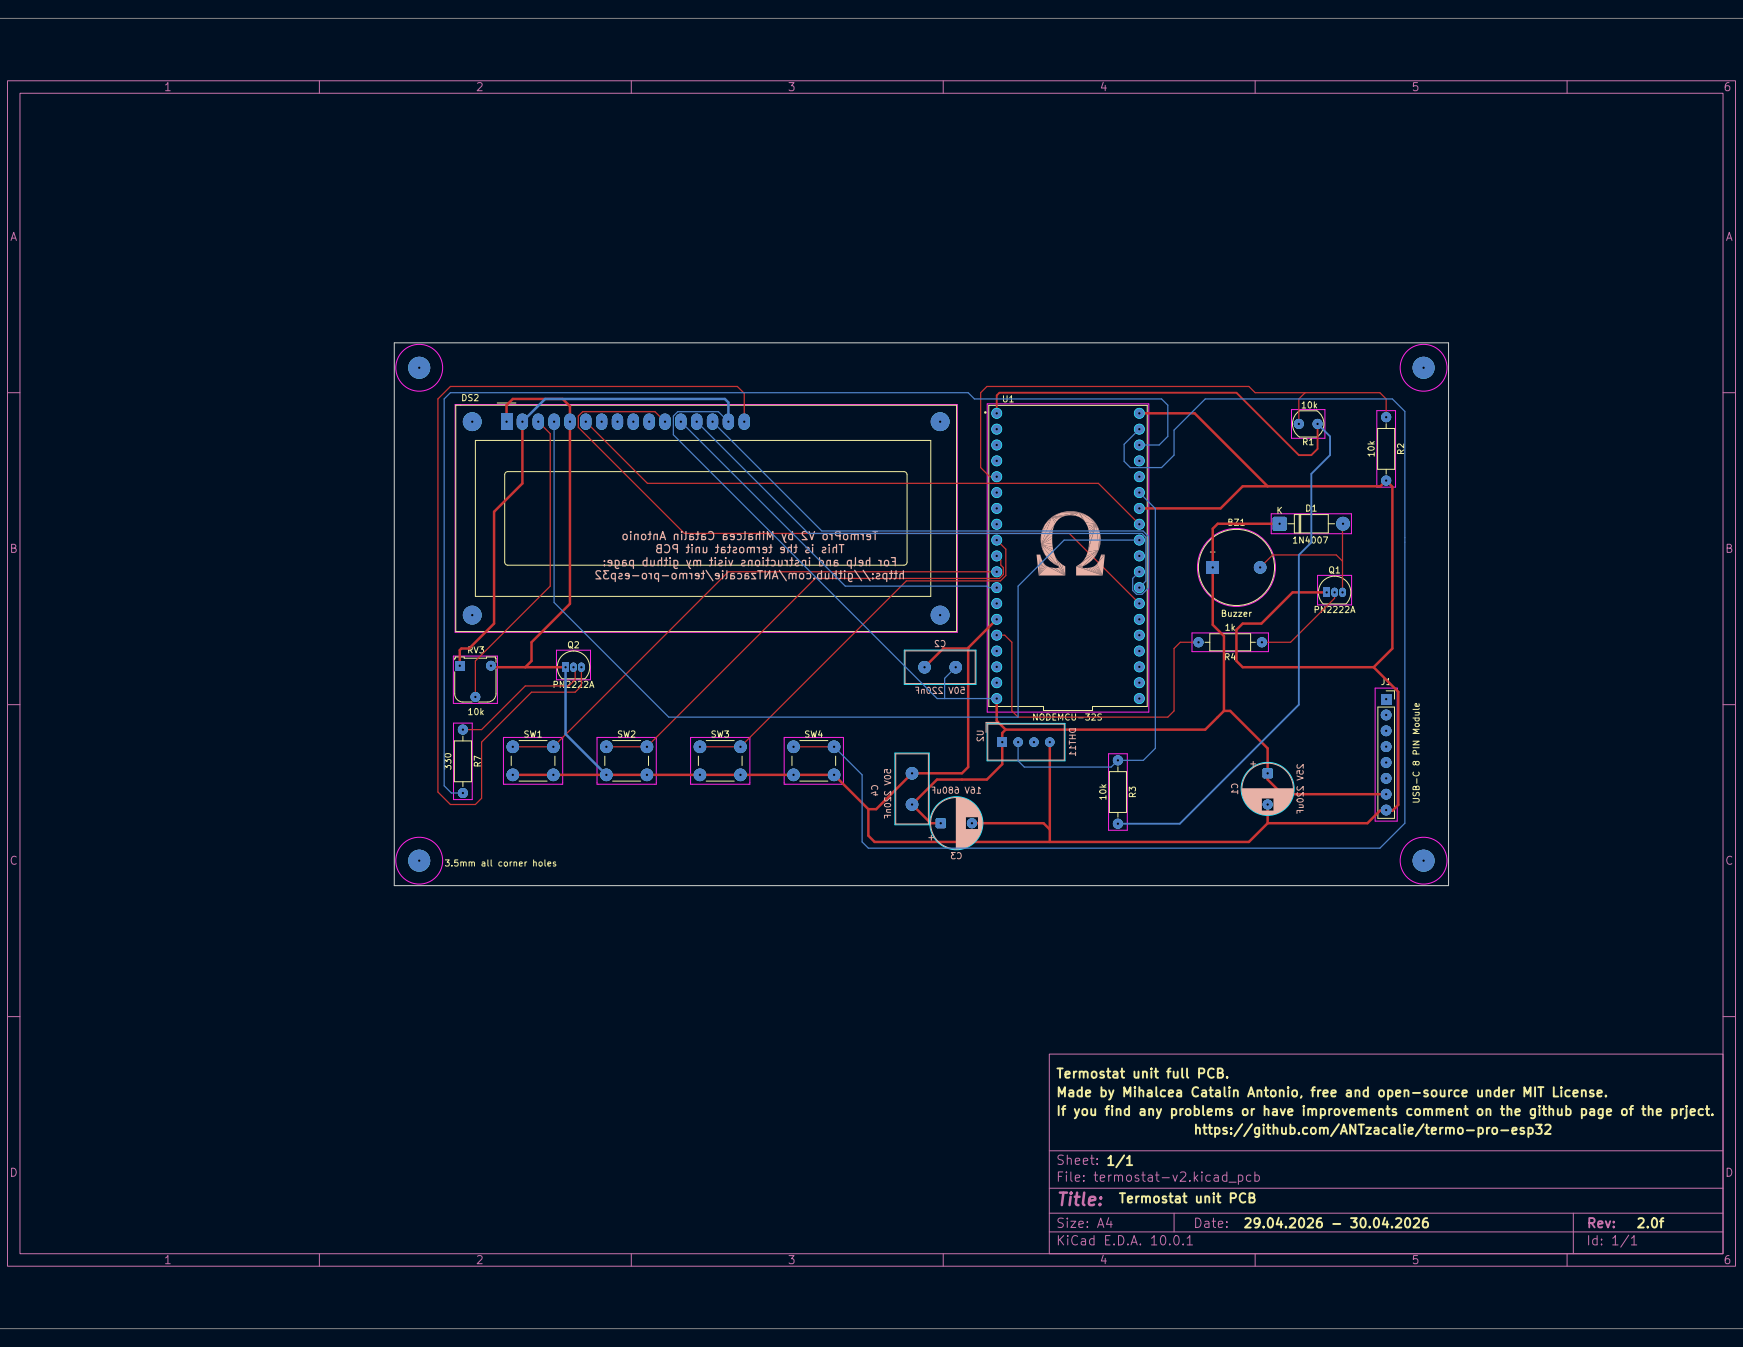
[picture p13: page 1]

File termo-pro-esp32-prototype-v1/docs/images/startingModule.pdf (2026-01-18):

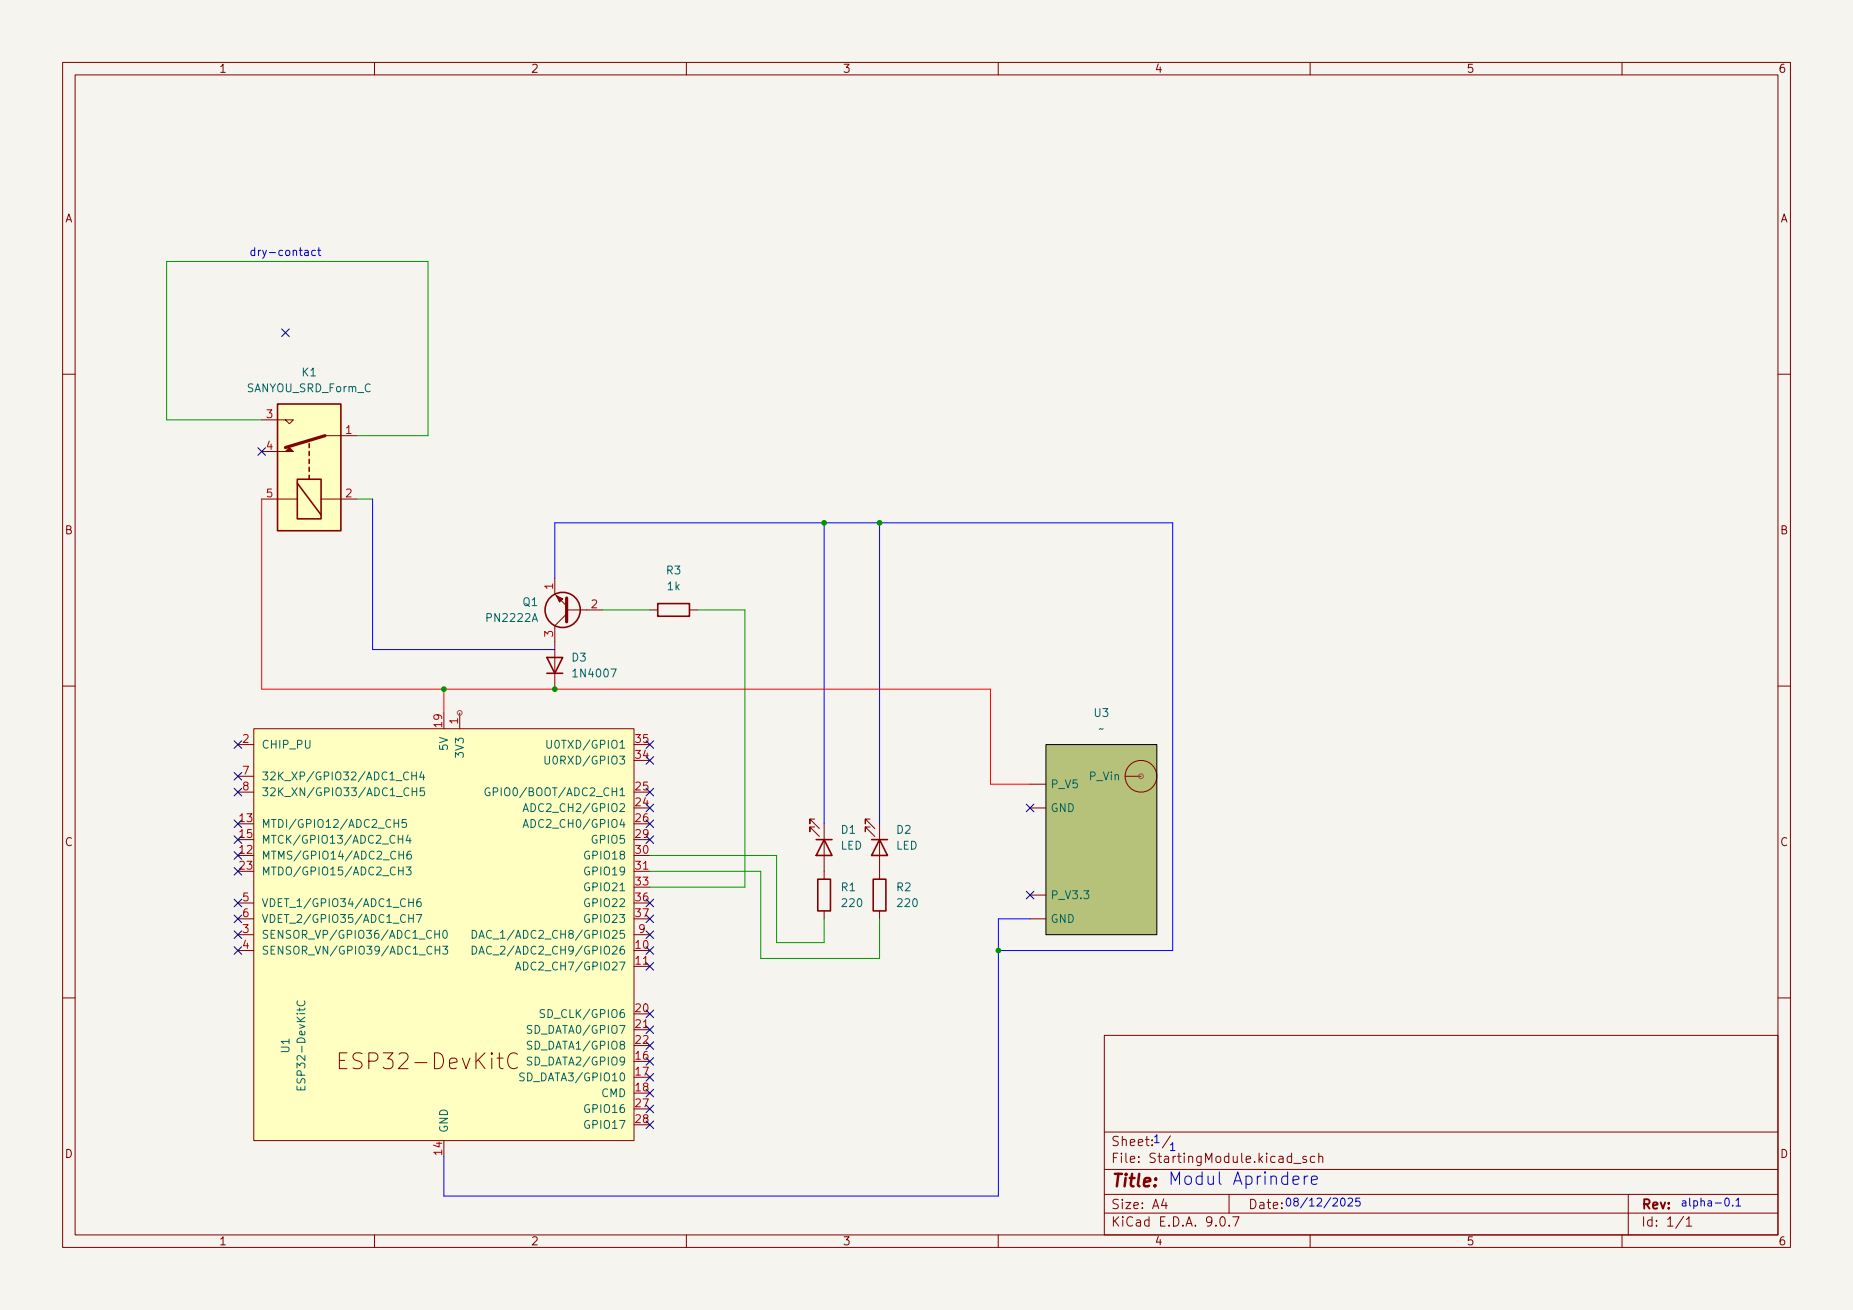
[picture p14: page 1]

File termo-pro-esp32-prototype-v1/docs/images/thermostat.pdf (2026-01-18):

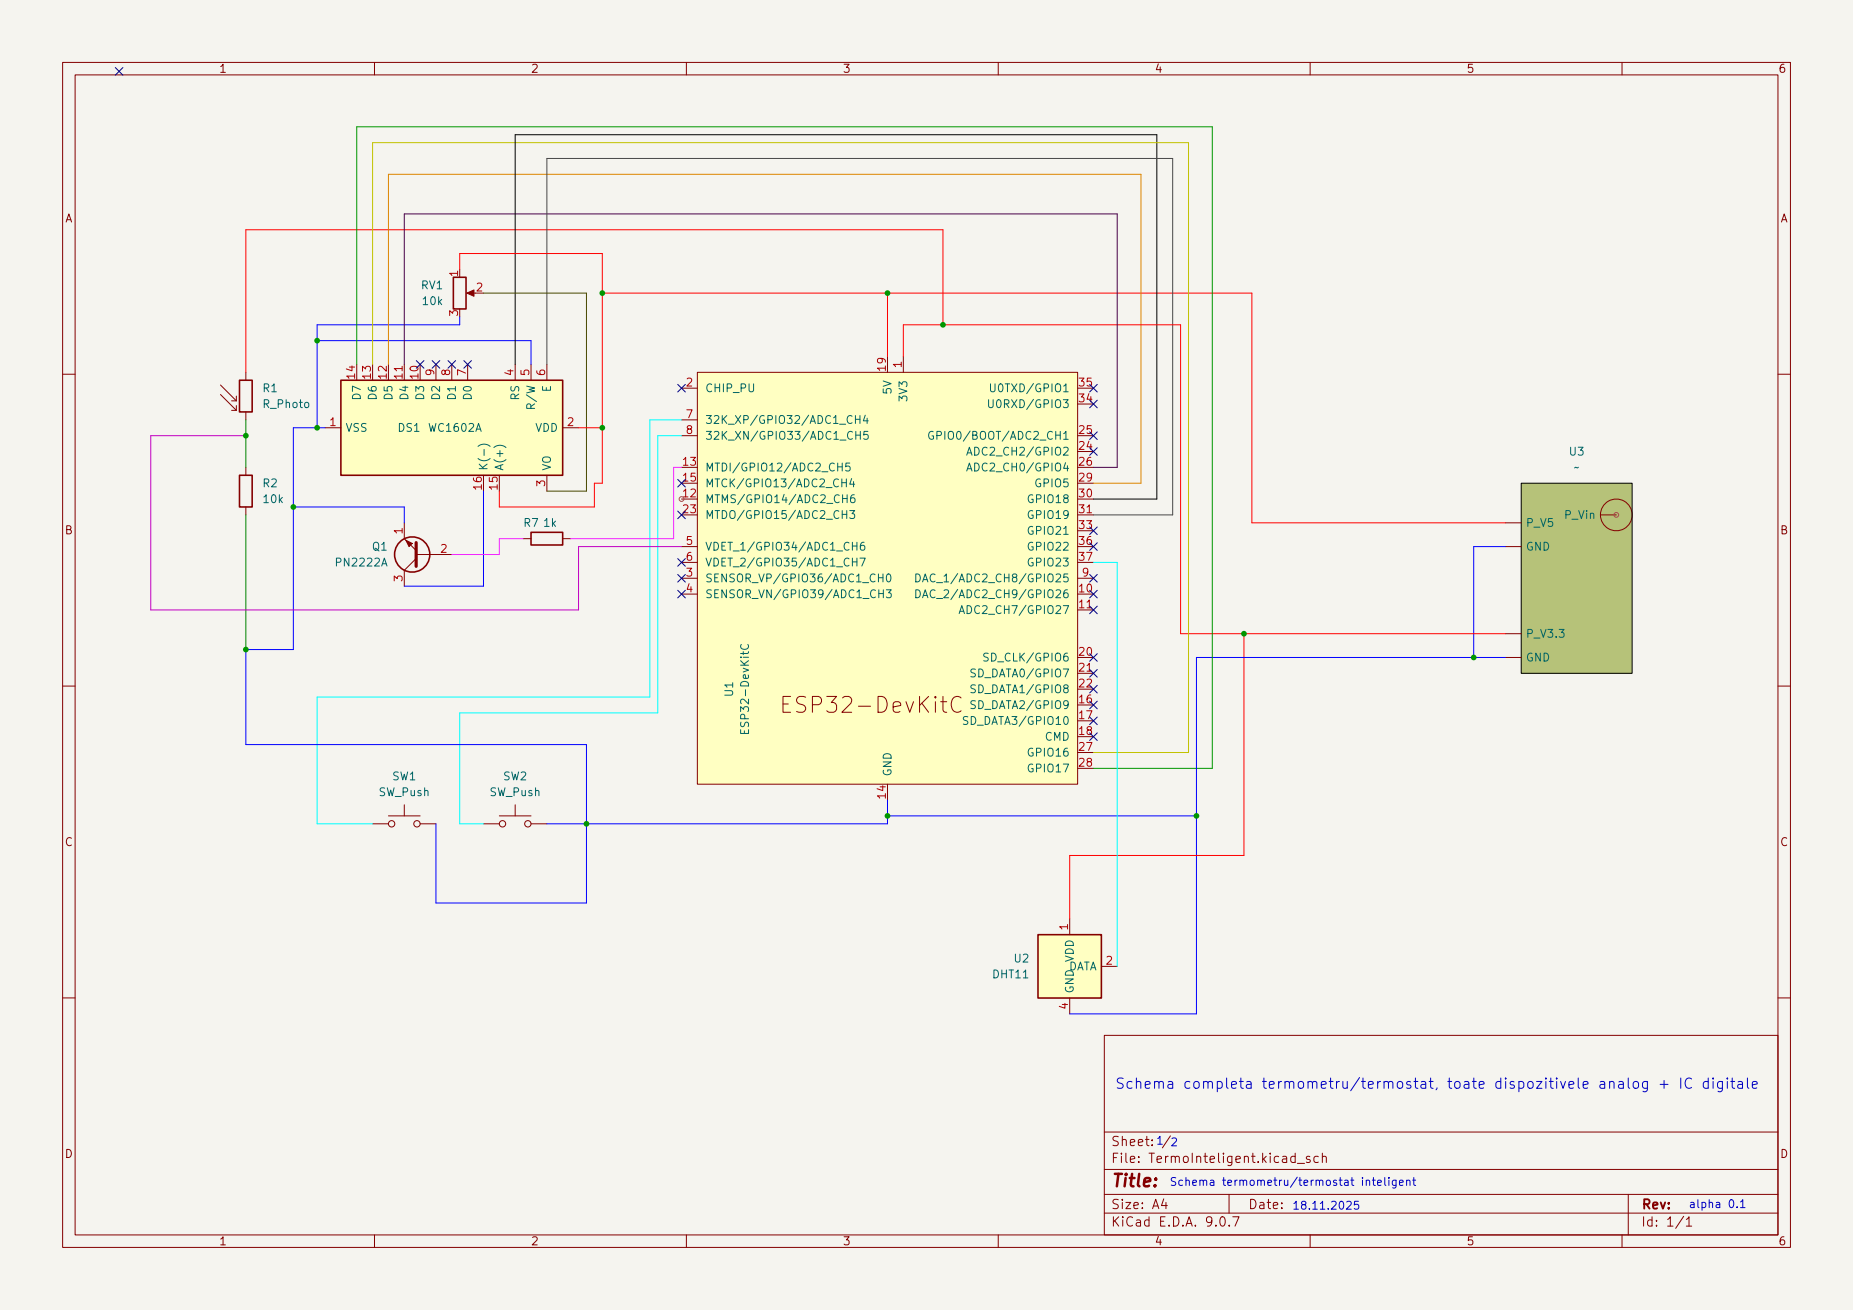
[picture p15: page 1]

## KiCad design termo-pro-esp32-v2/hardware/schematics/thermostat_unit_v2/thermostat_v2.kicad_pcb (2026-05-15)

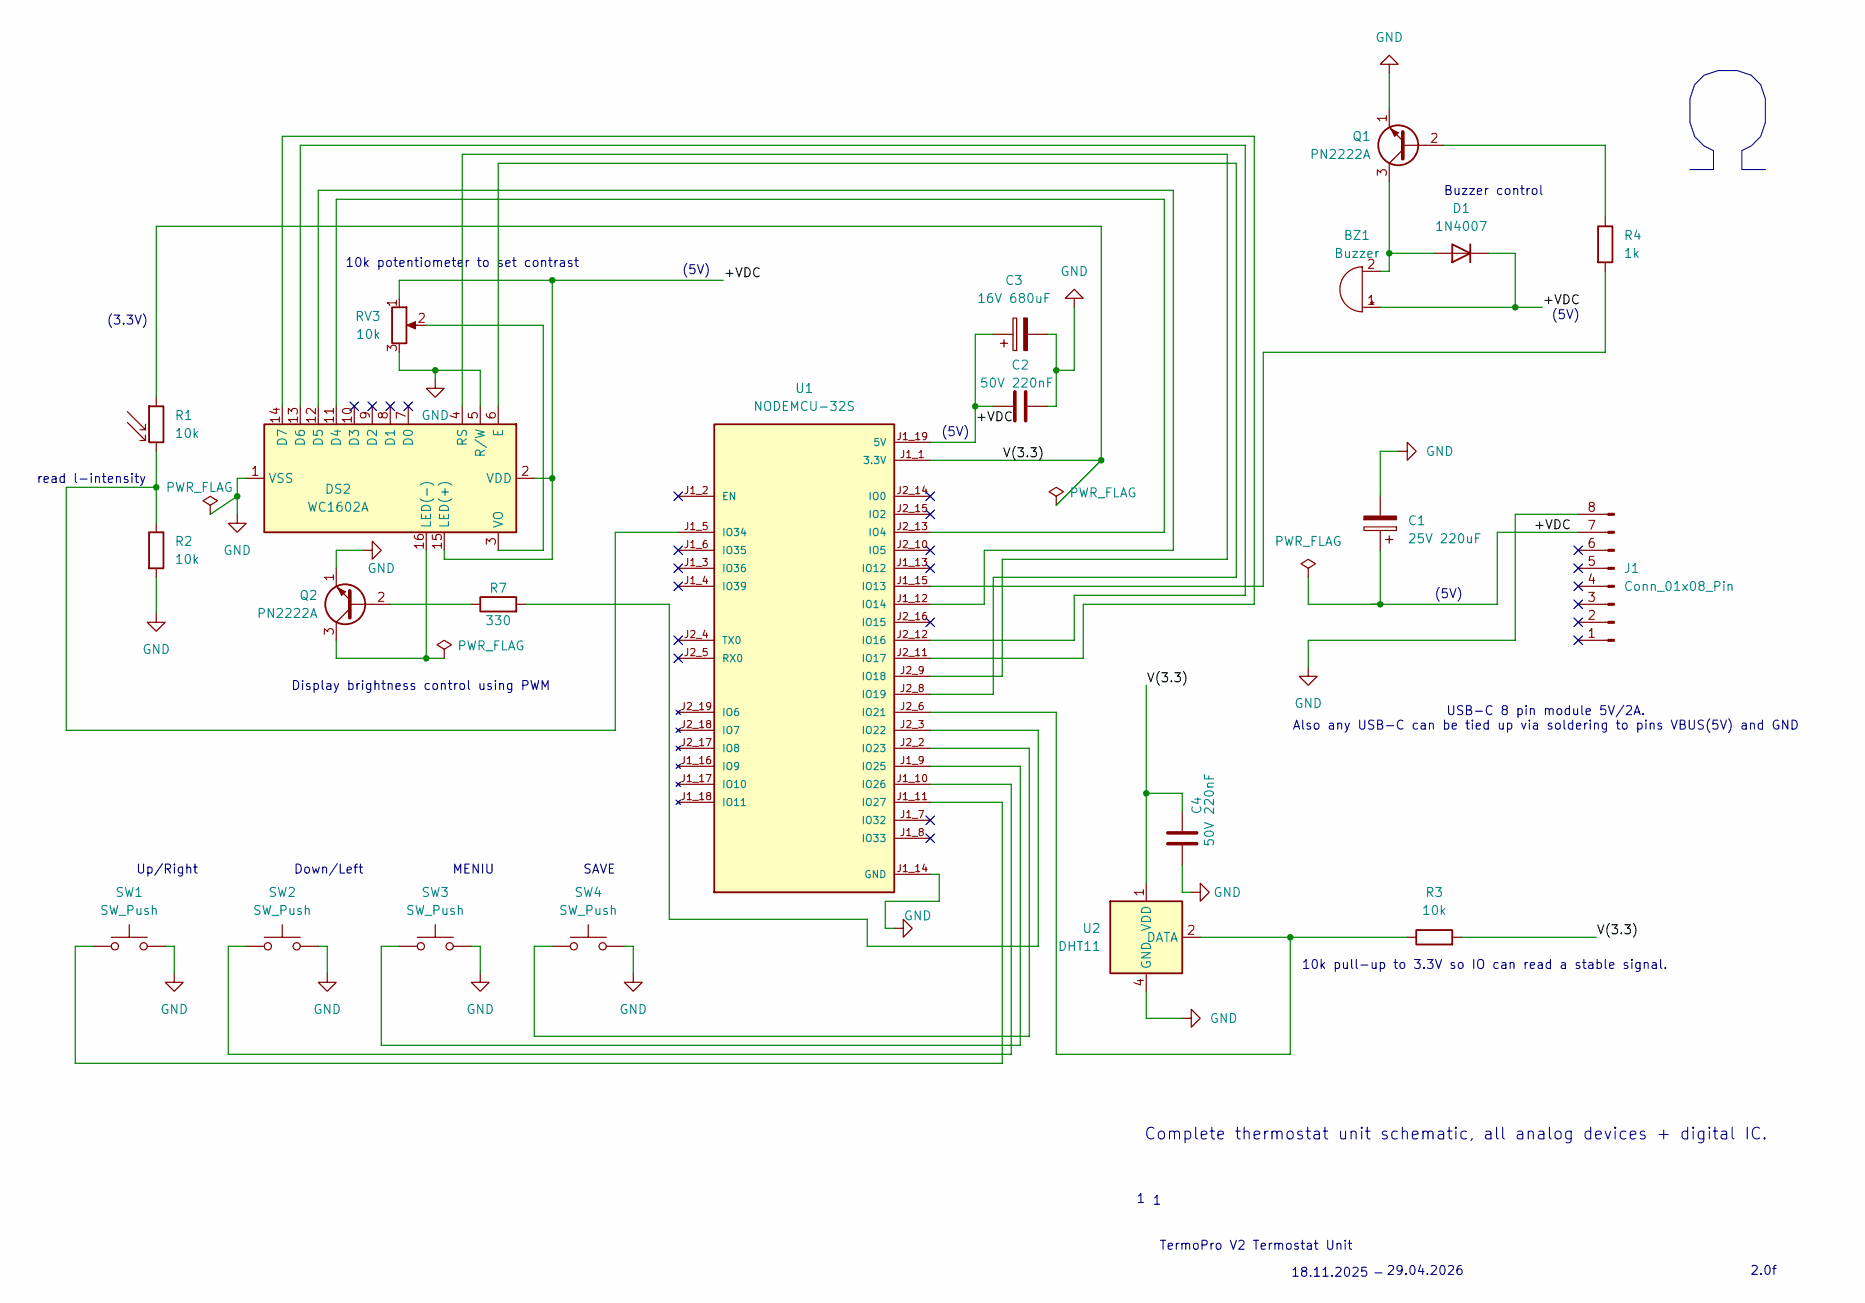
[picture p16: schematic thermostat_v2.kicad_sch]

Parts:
BZ1: Buzzer; Buzzer_12x9.5RM7.6
C1: 25V 220uF; CP_Radial_D8.0mm_P5.00mm
C2, C4: 50V 220nF; C_Disc_D11.0mm_W5.0mm_P5.00mm
C3: 16V 680uF; CP_Radial_D8.0mm_P5.00mm
D1: 1N4007; D_DO-41_SOD81_P10.16mm_Horizontal
DS2: WC1602A
J1: Conn_01x08_Pin; PinSocket_1x08_P2.54mm_Vertical
Q1, Q2: PN2222A; TO-92_Inline
R1: 10k; R_LDR_5.0x4.1mm_P3mm_Vertical
R2, R3: 10k; R_Axial_DIN0207_L6.3mm_D2.5mm_P10.16mm_Horizontal
R4: 1k; R_Axial_DIN0207_L6.3mm_D2.5mm_P10.16mm_Horizontal
R7: 330; R_Axial_DIN0207_L6.3mm_D2.5mm_P10.16mm_Horizontal
RV3: 10k; Potentiometer_Runtron_RM-065_Vertical
SW1, SW2, SW3, SW4: SW_Push; SW_PUSH_6mm
U1: NODEMCU-32S; MODULE_NODEMCU-32S; PARTREV V1
U2: DHT11; Aosong_DHT11_5.5x12.0_P2.54mm

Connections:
/+VDC: BZ1.1 (+), C1.1, C2.1, C3.1, D1.1 (K), DS2.2 (VDD), DS2.15 (LED(+)), J1.7, RV3.1, U1.J1_19 (5V)
/V(3.3): C4.2, R1.1, R3.2, U1.J1_1 (3.3V), U2.1 (VDD)
GND: C1.2, C2.2, C3.2, C4.1, DS2.1 (VSS), DS2.5 (R/W), J1.8, Q1.1 (E), Q2.1 (E), R2.2, RV3.3, SW1.2, SW2.2, SW3.2, SW4.2, U1.J1_14 (GND), U1.J2_1 (GND), U1.J2_7 (GND), U2.4 (GND)
unnamed: BZ1.2 (-), D1.2 (A), Q1.3 (C)
unnamed: DS2.11 (D4), U1.J2_13 (IO4)
unnamed: DS2.12 (D5), U1.J1_12 (IO14)
unnamed: DS2.13 (D6), U1.J2_12 (IO16)
unnamed: DS2.14 (D7), U1.J2_11 (IO17)
unnamed: DS2.6 (E), U1.J2_8 (IO19)
unnamed: DS2.16 (LED(-)), Q2.3 (C)
unnamed: DS2.4 (RS), U1.J2_9 (IO18)
unnamed: DS2.3 (VO), RV3.2
unnamed: Q1.2 (B), R4.1
unnamed: Q2.2 (B), R7.1
unnamed: R4.2, U1.J1_15 (IO13)
unnamed: R3.1, U1.J2_6 (IO21), U2.2 (DATA)
unnamed: R7.2, U1.J2_3 (IO22)
unnamed: SW4.1, U1.J2_2 (IO23)
unnamed: SW3.1, U1.J1_9 (IO25)
unnamed: SW2.1, U1.J1_10 (IO26)
unnamed: SW1.1, U1.J1_11 (IO27)
unnamed: R1.2, R2.1, U1.J1_5 (IO34)

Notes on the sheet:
2.0f
(5V)
18.11.2025
read l-intensity
10k pull-up to 3.3V so IO can read a stable signal.
Up/Right Down/Left MENIU SAVE
Buzzer control
10k potentiometer to set contrast
(3.3V)
Display brightness control using PWM
USB-C 8 pin module 5V/2A. Also any USB-C can be tied up via soldering to pins VBUS(5V) and GND
29.04.2026
TermoPro V2 Termostat Unit
Complete thermostat unit schematic, all analog devices + digital IC.

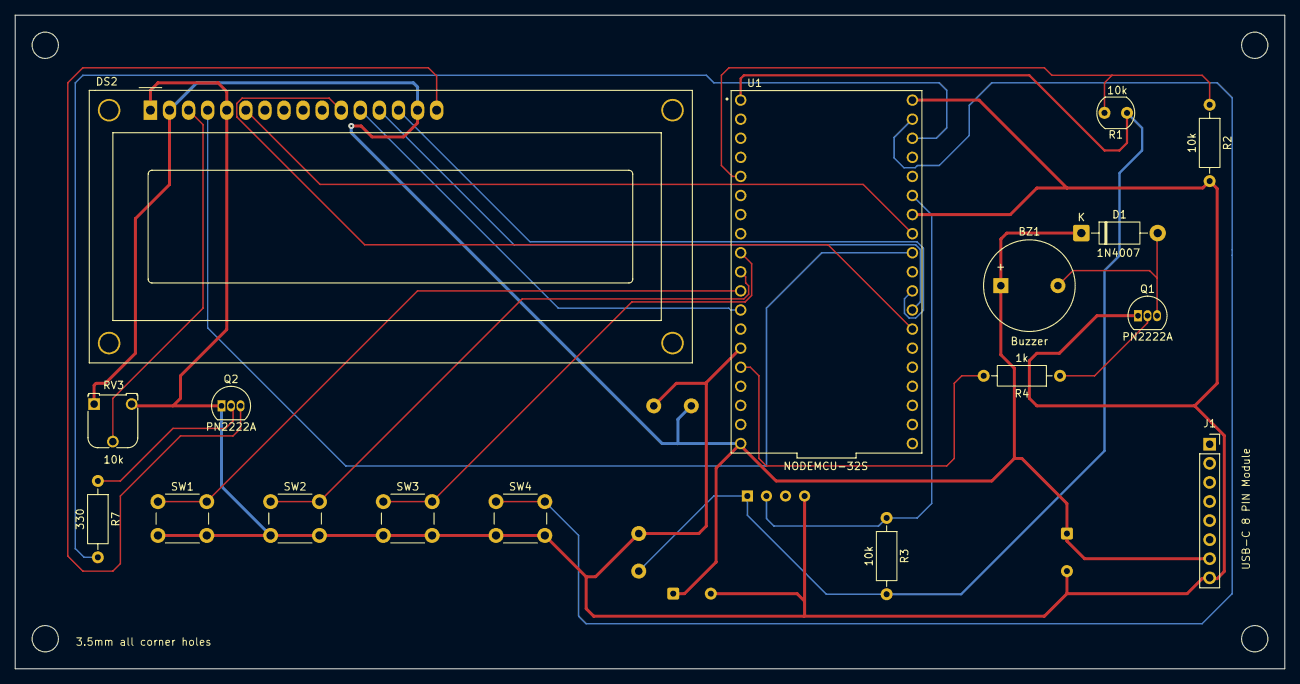
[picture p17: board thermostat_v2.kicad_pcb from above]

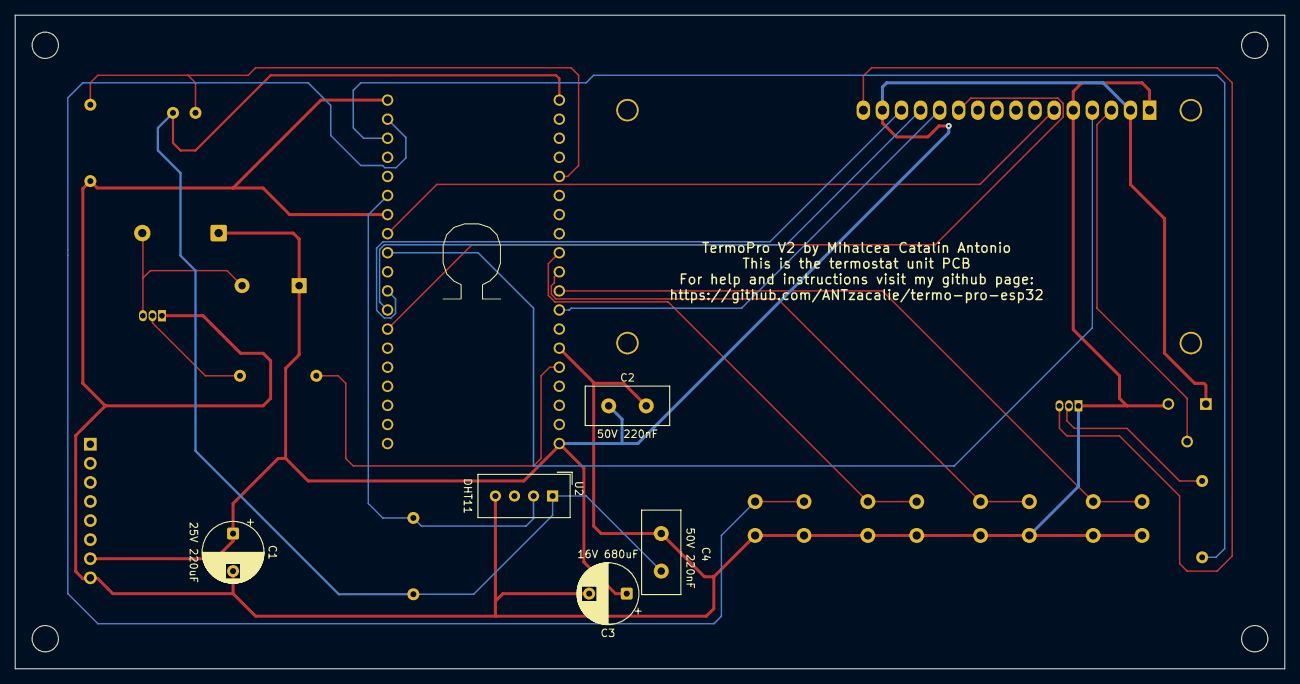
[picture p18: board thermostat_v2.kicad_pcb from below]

Board: 2 copper layers, 169.0 x 87.0 mm, 22 parts (5 on the bottom side), 22 nets.

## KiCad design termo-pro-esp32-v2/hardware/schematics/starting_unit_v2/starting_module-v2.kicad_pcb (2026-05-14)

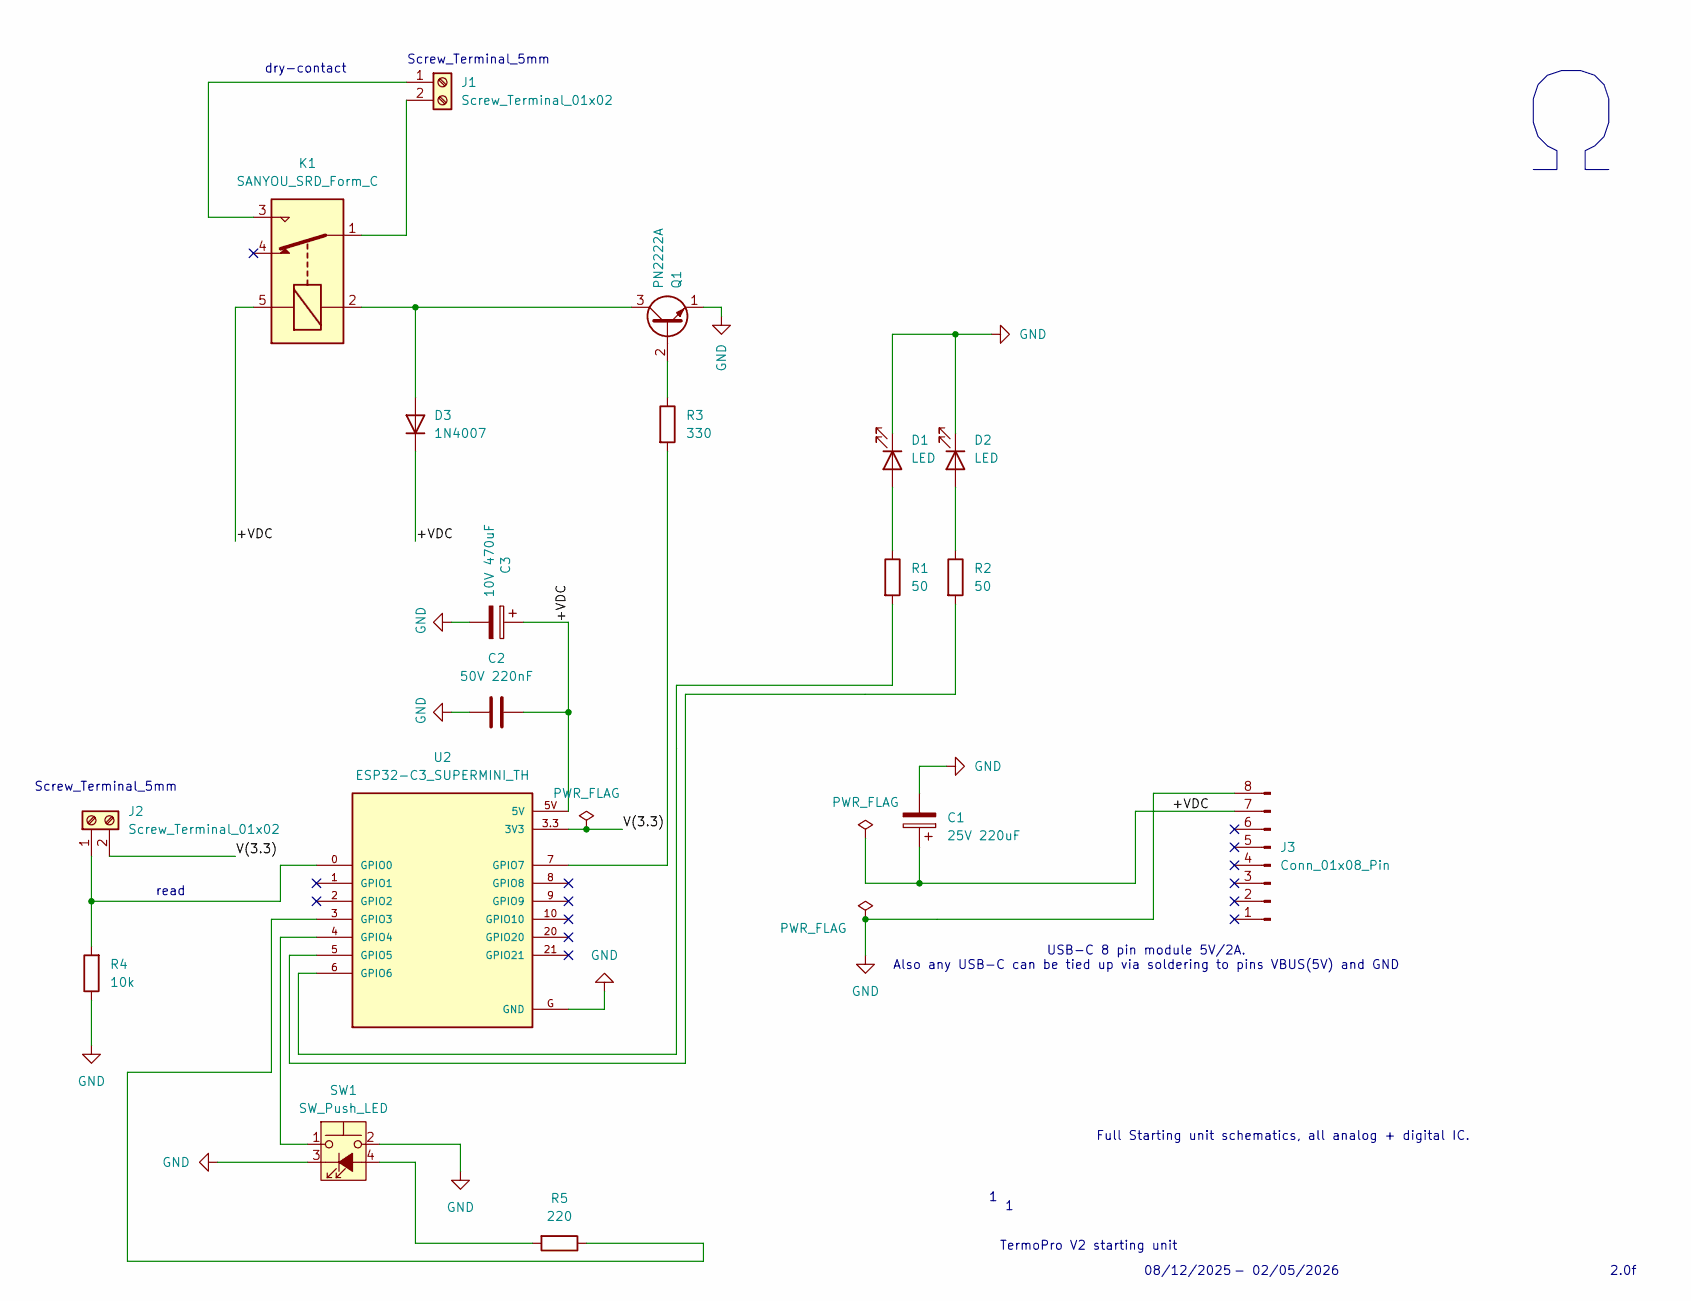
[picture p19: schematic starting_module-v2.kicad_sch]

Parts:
C1: 25V 220uF; CP_Radial_D8.0mm_P5.00mm
C2: 50V 220nF; C_Disc_D11.0mm_W5.0mm_P5.00mm
C3: 10V 470uF; CP_Radial_D8.0mm_P5.00mm
D1, D2: LED; LED_Rectangular_W5.0mm_H2.0mm
D3: 1N4007; D_DO-41_SOD81_P10.16mm_Horizontal
J1, J2: Screw_Terminal_01x02; TerminalBlock_RND_205-00232_1x02_P5.08mm_Horizontal
J3: Conn_01x08_Pin; PinSocket_1x08_P2.54mm_Vertical
K1: SANYOU_SRD_Form_C; Relay_SPDT_SANYOU_SRD_Series_Form_C
Q1: PN2222A; TO-92_Inline
R1, R2: 50; R_Axial_DIN0207_L6.3mm_D2.5mm_P10.16mm_Horizontal
R3: 330; R_Axial_DIN0207_L6.3mm_D2.5mm_P10.16mm_Horizontal
R4: 10k; R_Axial_DIN0207_L6.3mm_D2.5mm_P10.16mm_Horizontal
R5: 220; R_Axial_DIN0207_L6.3mm_D2.5mm_P10.16mm_Horizontal
SW1: SW_Push_LED; SW_PUSH-12mm
U2: ESP32-C3_SUPERMINI_TH; MODULE_ESP32-C3_SUPERMINI_TH

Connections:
/+VDC: C1.1, C2.1, C3.1, D3.1 (K), J3.7, K1.5, U2.5V
/V(3.3): J2.2, U2.3.3 (3V3)
GND: C1.2, C2.2, C3.2, D1.1 (K), D2.1 (K), J3.8, Q1.1 (E), R4.1, SW1.2, SW1.3 (K), U2.G (GND)
unnamed: D1.2 (A), R1.1
unnamed: D2.2 (A), R2.1
unnamed: D3.2 (A), K1.2, Q1.3 (C)
unnamed: J1.1, K1.3
unnamed: J1.2, K1.1
unnamed: J2.1, R4.2, U2.0 (GPIO0)
unnamed: Q1.2 (B), R3.1
unnamed: R5.2, SW1.4 (A)
unnamed: R5.1, U2.3 (GPIO3)
unnamed: SW1.1, U2.4 (GPIO4)
unnamed: R2.2, U2.5 (GPIO5)
unnamed: R1.2, U2.6 (GPIO6)
unnamed: R3.2, U2.7 (GPIO7)

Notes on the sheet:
read
Screw_Terminal_5mm
2.0f
- 02/05/2026
dry-contact
08/12/2025
TermoPro V2 starting unit
Full Starting unit schematics, all analog + digital IC.
USB-C 8 pin module 5V/2A. Also any USB-C can be tied up via soldering to pins VBUS(5V) and GND

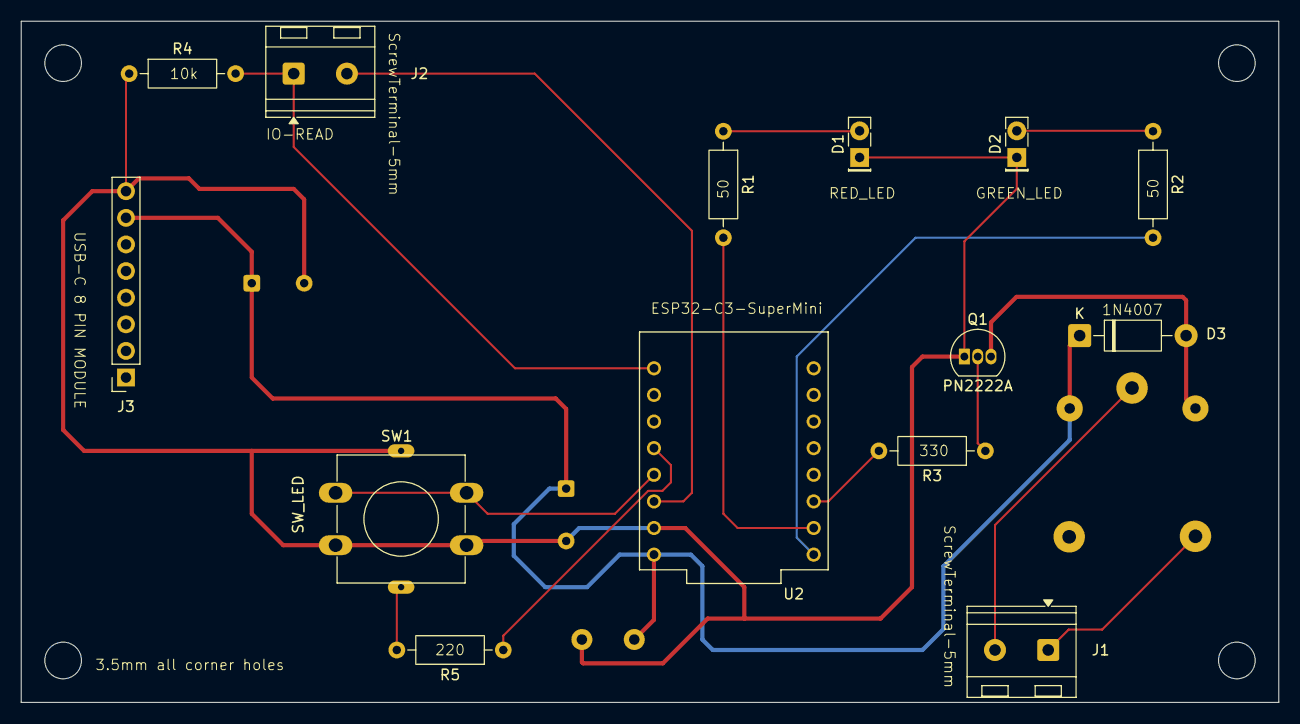
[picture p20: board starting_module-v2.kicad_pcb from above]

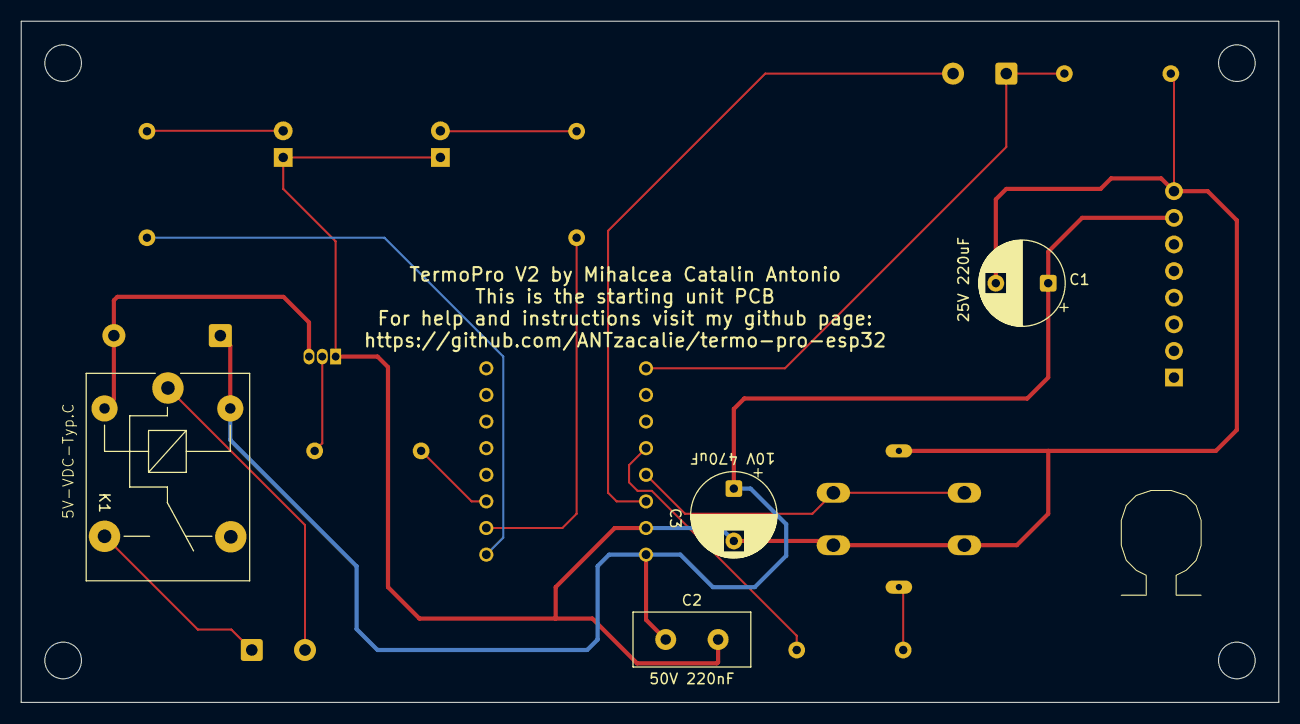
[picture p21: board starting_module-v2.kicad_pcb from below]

Board: 2 copper layers, 120.0 x 65.0 mm, 18 parts (4 on the bottom side), 16 nets.

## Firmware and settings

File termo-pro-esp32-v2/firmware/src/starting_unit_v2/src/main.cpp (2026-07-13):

/*
 * starting-module-c3.cpp
 * ESP32-C3-SuperMini  —  ESP-IDF >= 5.x
 *
 * GPIO MAP
 * --------
 * GPIO0  → NTC thermistor (ADC input only, 10 k pull-down on board)
 * GPIO1  → unconnected
 * GPIO2  → unconnected
 * GPIO3  → resistor → 12 mm LED-button (+)  [auxiliary, output only here]
 * GPIO5  → resistor → green LED
 * GPIO6  → resistor → red   LED
 * GPIO7  → resistor → PN2222A base  (motor/load switch)
 * 3.3 V  → NTC sensor VCC
 * 5 V    → board VIN
 */
#include <atomic>
#include <string.h>
#include <string>
#include "freertos/FreeRTOS.h"
#include "freertos/task.h"
#include "esp_system.h"
#include "esp_wifi.h"
#include "esp_now.h"
#include "esp_log.h"
#include "nvs_flash.h"
#include "driver/gpio.h"

// ### TAG ####################################################################
static const char* TAG = "LOG[SU]";

// ### PIN DEFINITIONS ########################################################
static constexpr gpio_num_t PIN_TEMP_SENSE = GPIO_NUM_0;   // ADC input  (NTC);
static constexpr gpio_num_t M_PIN_BTN_LED  = GPIO_NUM_3;   // manual_start_button LED control pin;
static constexpr gpio_num_t M_PIN_BTN      = GPIO_NUM_4;   // manual_start_button logic input;
static constexpr gpio_num_t PIN_LED_GREEN  = GPIO_NUM_5;   // ON LED;
static constexpr gpio_num_t PIN_LED_RED    = GPIO_NUM_6;   // OFF LED;
static constexpr gpio_num_t PIN_TRANSISTOR = GPIO_NUM_7;   // PN2222A base -> RELAY;

// ### ESP-NOW PEER  (replace with real MAC before flashing!) ##################
static uint8_t receiver_mac[6] = { 0x00, 0x00, 0x00, 0x00, 0x00, 0x00 };

// ### ERROR CODES ############################################################
typedef enum : uint8_t {

    UNIT_CK            = 0,
    // communication
    ERR_LEN_INVALID    = 10,
    ERR_DATA_INVALID   = 11,
    // system
    ERR_BROWNOUT       = 30,
    ERR_REBOOTED       = 31,
    ERR_WATCHDOG_RESET = 32

} UNIT_P_ERR;

// ### PAYLOAD STRUCTS ########################################################
struct [[gnu::packed]] esp_data_receive {
    bool execute;
};

struct [[gnu::packed]] esp_data_state {
    bool    SETUP_UNIT_CK;
    uint8_t UNIT_ERR;
};

struct [[gnu::packed]] esp_data_sensor { // IMPLEMENT LOGIC ON THE THERMOSTAT UNIT SIDE AND ALSO EXT_SENSOR LOGIC HERE;
    uint8_t SENSOR_CK;
    float   EXT_TEMP_VAL;
};

// ### MODULE STATE ############################################################
static std::atomic<bool> is_on      = false;
static int           retry_counter  = 0;
static uint8_t       last_error     = UNIT_CK;
static esp_data_state data_sent      = {};


// DELAY
void delay(int d) {
    vTaskDelay(pdMS_TO_TICKS(d));
}

// ### GPIO HELPERS ############################################################
std::atomic<bool> manual_ovveride = false;

static inline void set_load(bool on, int8_t arg)
{

    if(!manual_ovveride.load() && !arg) {

        gpio_set_level(PIN_TRANSISTOR, on ? 1 : 0);
        gpio_set_level(PIN_LED_GREEN,  on ? 1 : 0);
        gpio_set_level(PIN_LED_RED,    on ? 0 : 1);
        ESP_LOGI(TAG, "AUTO_START");

    } else if(arg) {

        gpio_set_level(PIN_TRANSISTOR, on ? 1 : 0);
        gpio_set_level(PIN_LED_GREEN,  on ? 1 : 0);
        gpio_set_level(PIN_LED_RED,    on ? 0 : 1);
        ESP_LOGI(TAG, "MANUAL_START");

    }

}

// ### 12mm_LED ############################################################
static void aux_button_led_on()
{

    gpio_set_level(M_PIN_BTN_LED, 1);

}

static void aux_button_led_off()
{

    gpio_set_level(M_PIN_BTN_LED, 0);

}

// ### LOAD CONTROL ############################################################
static void start()
{
    is_on.store(true);
    set_load(true, 0);
    ESP_LOGI(TAG, "LED_G_ON");
}

static void stop()
{
    is_on.store(false);
    set_load(false, 0);
    ESP_LOGI(TAG, "LED_G_OFF");
}

// ### ESP-NOW SEND ############################################################
static void espnow_send(uint8_t error)
{

    /*
    
        MODIFIED FOR 2 different packet types
    
    */
    data_sent.SETUP_UNIT_CK = true;
    data_sent.UNIT_ERR      = error;

    esp_err_t ret = esp_now_send(receiver_mac, (const uint8_t*)&data_sent, sizeof(data_sent));
    if (ret != ESP_OK) {

        ESP_LOGE(TAG, "esp_now_send failed: %s", esp_err_to_name(ret));

    }

}

// ### ERROR HANDLER ###########################################################
static void handle_error(uint8_t error)
{

    last_error = error;

    if (retry_counter < 10) {

        retry_counter++;
        espnow_send(error);

    } else {

        ESP_LOGE(TAG, "Retry limit hit - restarting");
        esp_restart();

    }

}

// ### ESP-NOW CALLBACKS #######################################################

// IDF 5.x receive callback signature
static void on_receive(const esp_now_recv_info_t* recv_info, const uint8_t*data, int len)
{

    if (len != (int)sizeof(esp_data_receive)) {

        handle_error(ERR_LEN_INVALID);
        return;

    }

    esp_data_receive pkt;
    memcpy(&pkt, data, sizeof(pkt));

    if (pkt.execute) {

        start();

    } else {

        stop();

    }

}

static void on_sent(const uint8_t *mac_addr, esp_now_send_status_t status)
{

    if (status == ESP_NOW_SEND_SUCCESS) {

        retry_counter = 0;
        
    } else {

        handle_error(last_error);

    }

}

// ### BOOT STATUS #############################################################
static uint8_t report_boot_status()
{
    switch (esp_reset_reason()) 
    {
        case ESP_RST_BROWNOUT:
            return ERR_BROWNOUT;

        case ESP_RST_WDT:
        case ESP_RST_TASK_WDT:
            return ERR_WATCHDOG_RESET;

        case ESP_RST_POWERON:
            return UNIT_CK;

        default:                
            return ERR_REBOOTED;
    }
}

// ### GPIO INIT ###############################################################
static void gpio_init_all()
{

    // inputs: 12mm button
    gpio_set_direction(M_PIN_BTN, GPIO_MODE_INPUT);
    gpio_set_pull_mode(M_PIN_BTN, GPIO_PULLUP_ONLY);

    // outputs: transistor, LEDs, button-LED
    gpio_config_t out_cfg = {

        .pin_bit_mask = (1ULL << PIN_TRANSISTOR) |
                        (1ULL << PIN_LED_GREEN)  |
                        (1ULL << PIN_LED_RED)    |
                        (1ULL << M_PIN_BTN_LED),
        .mode         = GPIO_MODE_OUTPUT,
        .pull_up_en   = GPIO_PULLUP_DISABLE,
        .pull_down_en = GPIO_PULLDOWN_DISABLE,
        .intr_type    = GPIO_INTR_DISABLE,

    };

    gpio_config(&out_cfg);

    // safe defaults
    gpio_set_level(PIN_TRANSISTOR, 0);
    gpio_set_level(PIN_LED_GREEN,  0);
    gpio_set_level(PIN_LED_RED,    1);   // RED on at rest (load off)

    // GPIO0 is input-only on ESP32-C3; no config call needed —
    // the pin floats as ADC1_CH0 / input; the external 10 k sets the bias.

}

// ### WIFI / ESP-NOW INIT #####################################################
static void wifi_espnow_init()
{

    // NVS required by Wi-Fi driver
    esp_err_t ret = nvs_flash_init();
    if (ret == ESP_ERR_NVS_NO_FREE_PAGES || ret == ESP_ERR_NVS_NEW_VERSION_FOUND) {

        nvs_flash_erase();
        nvs_flash_init();
        
    }

    // Minimal Wi-Fi init (ESP-NOW needs the radio)
    wifi_init_config_t cfg = WIFI_INIT_CONFIG_DEFAULT();
    ESP_ERROR_CHECK(esp_netif_init());
    ESP_ERROR_CHECK(esp_event_loop_create_default());
    ESP_ERROR_CHECK(esp_wifi_init(&cfg));
    ESP_ERROR_CHECK(esp_wifi_set_storage(WIFI_STORAGE_RAM));
    ESP_ERROR_CHECK(esp_wifi_set_mode(WIFI_MODE_STA));
    ESP_ERROR_CHECK(esp_wifi_start());

    // ESP-NOW
    if (esp_now_init() != ESP_OK) {

        ESP_LOGE(TAG, "UNIT_START failed — restarting");
        esp_restart();

    }

    ESP_ERROR_CHECK(esp_now_register_recv_cb(on_receive));
    ESP_ERROR_CHECK(esp_now_register_send_cb(on_sent));

    esp_now_peer_info_t peer = {};
    memcpy(peer.peer_addr, receiver_mac, 6);
    peer.channel = 0;
    peer.encrypt = false;
    ESP_ERROR_CHECK(esp_now_add_peer(&peer));

}

void manual_start(void *p) {

    while (true)
    {

        if(gpio_get_level(M_PIN_BTN) == 0) {

            if(!manual_ovveride) {

                manual_ovveride = true;
                aux_button_led_on();
                
                if(!is_on.load())
                    set_load(true, 1);

            } else {
                
                manual_ovveride = false;
                aux_button_led_off();

                if(!is_on.load())
                    set_load(false, 1);

            }

        }

        delay(100);

    }
    
}

/*

    LOGIC FOR EXTERNAL TEMPERATURE SENSOR TO BE IMPLEMENTED!
    - Pin init&atten&cali;
    - Read&Interpret value of the thermistor B3950 10k;
    - Send the temperature value to Thermostat Unit;
    - Thats al;

    void external_sensor(void *p) 
    {}

*/

// ### APP MAIN ################################################################
extern "C" void app_main()
{

    gpio_init_all();
    aux_button_led_off();       // latch auxiliary LED-button off;

    // wifi
    wifi_espnow_init();

    uint8_t boot_err = report_boot_status();
    if (boot_err != UNIT_CK) {

        ESP_LOGW(TAG, "Abnormal boot: error 0x%02X", boot_err);
        handle_error(boot_err);

    } else {

        // send clean-boot ok to controller-esp
        espnow_send(UNIT_CK);
        
    }

    delay(1000);
    xTaskCreatePinnedToCore(manual_start, "M_PIN_BTN",   4096, NULL, 15, NULL, 0); // importance 15;
    //     xTaskCreatePinnedToCore(external_sensor, "EXT_SENSOR",   8192, NULL, 10, NULL, 1); // importance 10;


}

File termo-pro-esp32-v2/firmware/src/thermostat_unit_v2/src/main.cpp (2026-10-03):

#include "thermostat.h"

//  GLOBAL DEFINITIONS  (extern declarations live in thermostat_var.h)

// retry & safety
int  counter        = 0;
int  failed_receive = 0;
bool last_command   = false;

// Receiver MAC — Starting Unit (replace with real MAC before flashing!)
uint8_t receiverMAC[6] = { 0xD4, 0x8A, 0xFC, 0xA2, 0xA0, 0xD8 };

// time / day-night
int day_start   = 5;    // 05:00
int night_start = 21;   // 21:00
int hour        = 0;
int minute      = 0;
int day         = 0;    // weekday 1-7 (Mon=1, Sun=7)

// program state
int  program_choice  = 0;
bool manual_control  = false;
int  record_flag     = 0;

// auto mode instance  (extern in thermostat_var.h)
auto_mode confort_mode;

// ESP-NOW class static instance pointer (defined in thermostat.h)
local* local::instance = nullptr;


//  PROGRAM INSTANCES
auto_mode program_auto;
prog_1    program1;
prog_2    program2;
prog_3    program3;
prog_4    program4;
basic     program0;

//  LCD BACKLIGHT BRIGHTNESS THRESHOLDS  (12-bit ADC values)
enum brightness_control : uint16_t {

    LOW_BC    = 1200,
    LOW_H_BC  = 1800,
    MEDIUM_BC = 2400,
    INTER_NC  = 2900,
    HIGH_BC   = 3400,
    ULTRA_BC  = 3800,
    ULTRA_H_BC = 4000

};


// Set the internal RTC from explicit hour/minute/weekday values.
// Uses a fixed dummy date (Mon 1 Jan 2024) shifted by weekday offset.
static void set_time(int h, int m, int weekday) {

    struct tm t = {};

    t.tm_year  = 2024 - 1900;
    t.tm_mon   = 0;
    t.tm_mday  = 1 + (weekday - 1); // align calendar weekday
    t.tm_hour  = h;
    t.tm_min   = m;
    t.tm_sec   = 0;
    t.tm_isdst = -1;

    time_t epoch = mktime(&t);

    struct timeval tv;
    tv.tv_sec  = epoch;
    tv.tv_usec = 0;

    settimeofday(&tv, nullptr);

}
 
// Read current time back from the internal RTC.
static void read_time(int &h, int &m, int &weekday) {

    time_t now = time(nullptr);
    struct tm ti;
    localtime_r(&now, &ti);

    h       = ti.tm_hour;
    m       = ti.tm_min;
    weekday = (ti.tm_wday == 0) ? 7 : ti.tm_wday; // Sun = 0 -> 7

}

// Returns 1 and sets record_flag=1 when heating should start.
int check_for_start(float current_temp, float start_temp) {

    if (current_temp <= start_temp) {
        record_flag = 1;
        return 1;
    }
    return 0;

}

// Returns 1 and sets record_flag=2 when heating should stop.
int check_for_stop(float current_temp, float stop_temp) {

    if (current_temp >= stop_temp) {
        record_flag = 2;
        return 1;
    }
    return 0;

}


//  CUSTOM LCD CHARACTERS(ARROW UP)
static uint8_t arrowUp[8] = {

    0b00100,
    0b01110,
    0b11111,
    0b00100,
    0b00100,
    0b00100,
    0b00100,
    0b00100

};

// Initial splash screen
void splash_1() {

    // splash screen 
    lcd_row_sel(0);
    lcd.print("TermoPro v2.0");
    lcd_row_sel(1);
    lcd.print("by ANTzacalie");
    delay_s(3000);

    lcd.clear();
    lcd_row_sel(0);
    lcd.print("For bugs go to");
    lcd_row_sel(1);
    lcd.print("---- GitHub ----");
    delay_s(1800);

}

// Secondary splash screen
void splash_2() {

    lcd_row_sel(0);
    lcd.print(" TermoPro v2.0 ");
    
    for(int i = 0; i < 16; i+=1) {

        lcd.setCursor(i, 1);
        lcd.print(".");
        delay_s(200);

    }

}

// MAIN
extern "C" void app_main() {

    // static ESP-NOW handler instance 
    static local command;
    local::instance = &command;

    // peripheral init 
    gpio_buttons_init();
    adc_ldr_init();
    ledc_backlight_init();

    // Wi-Fi + ESP-NOW 
    wifi_espnow_init();

    // DHT11 
    dht.begin();

    // LCD 
    lcd.begin(16, 2);
    lcd.clear();
    // custom arrow_up loaded into display
    lcd.createChar(0, arrowUp);

    // initial brightness 
    sensor.setBrightness(150);

    // NVS / preferences 
    storage.begin();

    delay_s(500); // stabilization

    splash_1();
    lcd.clear();
    splash_2();

    delay_s(1000);
    lcd.clear();

    while (true) {

        /*
                TEST
        */

        delay_s(5000);
        sensor.readTemperatureHumidity();
        lcd.print(sensor.getTemperature());

    }

}

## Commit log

2026-02-27 Enhance setup guide with hardware and GPIO details
    Added detailed instructions for hardware assembly and GPIO pin usage for the thermostat and starting module. Included notes on ESP32 specifications and relay connections.
2026-02-27 Revise wiring.md with structured tables
    Updated wiring documentation for ignition control and intelligent thermometer/thermostat module, including tabular format for clarity.
2026-02-27 Revise setup guide with GPIO and electrical details
    Expanded the setup guide with detailed GPIO configurations and electrical considerations for the thermostat and starting modules. Added warnings about different ESP32 variants and proper wiring pract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
    Remade the hole thing to look better and be more easy to understand and follow.
2026-02-27 Enhance README with firmware setup and MAC address details
    Updated the README to include detailed instructions for MAC address configuration and software setup for ESP32 boards.
2026-03-22 Add flashing instructions to README.md
    Added flashing instructions for ESP32 firmware.
2026-03-22 Update setup guide with GPIO details and warnings
    Added warnings and clarified GPIO pin assignments for components.
2026-04-08 Updated project
    V2 will include a better version and a way to build this termostat on a solid case.
    [StartingModule.kicad_sch, TermoInteligent.kicad_sch]
2026-04-09 start of TermoPro V2
    -Both schematics inspected, fixed electrical problems and simpliefied.
    -All older instruction deleted, new ones will be made when product will be finished.
    -Termostat unit upgraded from 2 to 4 buttons for better commands, use and standards.
    -Termostat code will be updated with new logic to handle 4 buttons, also some code efficiency and improvments too.
    -Bluetooth capab. will begin testing and mobile app interface and com logic testing.
    -Next pcb footprints for the parts used will be created.
    [starting_module-v2.kicad_pcb, starting_module-v2.kicad_sch, termostat-v2.kicad_pcb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]
2026-04-13 schematic redone and improvment.
    more to come...
    [starting_module-v2.kicad_sch, termostat-v2.kicad_sch]
2026-04-18 Firmware modification and complete schematics redone and improvement.
    All schematics have been redone.
    All components have footprints.
    Microcontrollers used ESP32S-38 NodeMCU and ESP32-C3-SuperMini.
    ESP8266 has been eliminated because of compatibility issues.
    Next phase is PCB design.
    [ESP32-C3_SUPERMINI_TH.step, starting_module-v2.kicad_sch, termostat-v2.kicad_sch]
2026-04-24 Final schematics and footprints for all components.
    - All schematics have been completed.
    - All components have footprints.
    Next:
    - Testing schematics for any errors phisically.
    - Making PCBs based on schmatics.
    - Android app for termostat parameteers control.
    [ESP32-C3 SuperMini_TH--3DModel-STEP-56544.STEP, external_temp_sensor.kicad_pcb, external_temp_sensor.kicad_sch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]
2026-04-27 Starting Unit PCB compleate.
    Some footprint issues were encountered on the initial unit PCB, regarding the ceramic capacitors and the 1×02 5.08 mm screw terminal.
    -In the thermostat schematic, the ceramic capacitors were updated to a disc footprint , as well in the starting unit scheme.
    -Thermostat PCB is currently in progress.
    [external_temp_sensor.kicad_sch, starting_module-v2.kicad_pcb, starting_module-v2.kicad_sch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]
2026-05-02 Fixed J2 traces, 3.3V was connected after RDT
    Starting unit schematic had a mistake made, 3.3V was before RDT leaving GPIO to read nothing , path mistake was fixed.
    Starting unit PCB modified and fixed from schematic.
    [BOM_starting_module-v2.csv, BOM_termostat-v2.csv, ESP32-C3 SuperMini_TH--3DModel-STEP-56544.STEP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]
2026-05-10 Hardware part of the project is finished.
    -DHT11 placement on thermostat unit fixed, pins trace redone.
    -USB-C port on thermostat unit placed closer to edge by 4mm.
    -Capacitors values recalculated and updated to closest common values, resistors values too.
    -Starting unit pcb redone traces as relay and caps have been moved to the back plate.
    -Starting & thermostat units PCB are done, inspected.
    -Ready for fabrication.
    [BOM_starting_module-v2.csv, BOM_termostat-v2.csv, cable_clipperFCStd.3mf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]
2026-05-10 folder structure changed
    [ESP32-C3 SuperMini_TH--3DModel-STEP-56544.STEP, ESP32-C3_SUPERMINI_TH.step, cable_clipperFCStd.3mf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]
2026-05-14 Removed circular LED and replaced them with rectangular ones.
    [ESP32-C3 SuperMini_TH--3DModel-STEP-56544.STEP, ESP32-C3_SUPERMINI_TH.step, cable_clipperFCStd.3mf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]
2026-05-14 Documentation changes
    Starting unit schematic and PCB has been updated for the 50 ohm resistors used for LED.
    gerber and drill files generated again.
    [starting_module-v2-B_Cu.gbr, starting_module-v2-B_Mask.gbr, starting_module-v2-B_Paste.gbr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]
2026-05-14 external temperature sensor enclosure modified
    [external_temperature_sensor_enclosure-BodyHole.3mf, xr.3mf]
2026-05-15 external enclosure changed for a better slim fit
2026-05-15 minor thermostat pcb and schematic fix , missed to put the 3.3V net to DHT11, put the 5V instead, mistake
    [thermostat_v2-B_Cu.gbr, thermostat_v2-B_Mask.gbr, thermostat_v2-B_Paste.gbr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]
2026-05-15 All electrical/PCB fixed
    -software is to be improved.
    -3d enclosure for thermostat and starting unit will be build.
    -ansambly when PCB is received
2026-05-23 PCB.zip files uploaded
    2-5 days until PCB are received
2026-05-26 porting Arduino Code to IDF
2026-05-27 Removed old reference firmware
    Will be replaced with platformio project and redone code.
    [main.cpp]
2026-05-30 added logic for 12mm button on su
2026-06-30 fixed platformio errors
    Pioarduino version 53 was the problem, moved to latest 55.03.39
    [main.cpp, thermostat.h, thermostat_var.h]
2026-07-26 fixed code related to old IDF version
    Added better splash screen;
    Moved logic from main.cpp to thermostat.h;
    Better code readability;
    [main.cpp, thermostat.h]
2026-10-17 Create README for ESP32 Smart Thermostat project
    Added detailed README for ESP32 Smart Thermostat project, including features, user interface guide, navigation, settings, special commands, and future roadmap.
2026-11-04 implemented ext_temp_sensor equation and calibration, for 32 samples
2026-11-05 chnaged platform from esp32dev to esp32C3mini
2026-11-05 removed power on reset from loop in testing
2026-11-05 added delay for switching to manual mode on/off

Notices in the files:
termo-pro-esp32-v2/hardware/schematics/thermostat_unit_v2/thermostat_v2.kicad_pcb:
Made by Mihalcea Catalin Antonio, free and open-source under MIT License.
